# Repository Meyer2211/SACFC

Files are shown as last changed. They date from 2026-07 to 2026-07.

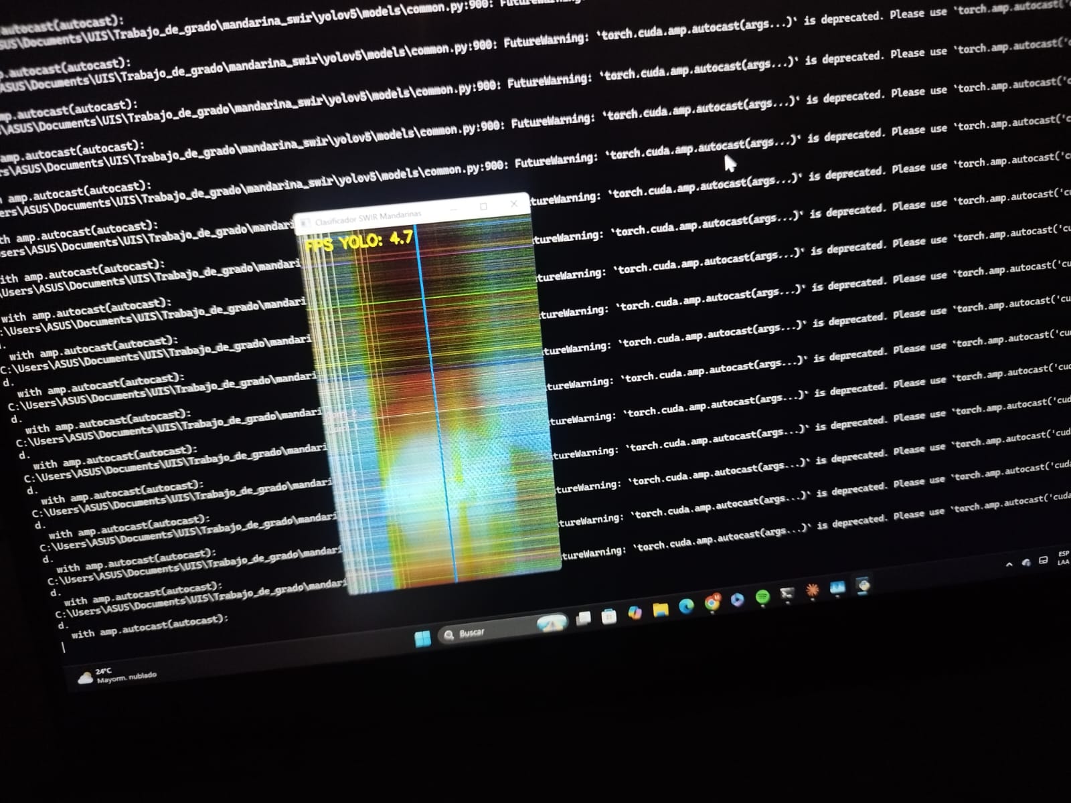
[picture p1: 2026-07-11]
SWIR/Pruebas_del_sistema_02_06_26/2_02_06_26.jpeg

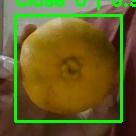
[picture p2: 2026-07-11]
RGB/Pruebas_Obtenidas/Image_processing/PAD_Dinamico/mandarina_3_MALA.jpg

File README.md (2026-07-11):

# SACFC

## Sistema Automático de Clasificación de Frutos Cítricos

## Descripción general

Este repositorio contiene el desarrollo de un trabajo de grado universitario centrado en un sistema de clasificación automática de mandarinas en tiempo real, orientado a una línea de banda transportadora. El sistema combina visión por computador para la detección y evaluación de calidad de la fruta con actuadores físicos (servomotores controlados por Arduino) para desviarla hacia carriles de fruta "buena" o "mala" según el resultado de la clasificación.

## Objetivo del proyecto

Diseñar e implementar un sistema capaz de detectar mandarinas sobre una banda transportadora, clasificar su calidad de forma automática y accionar físicamente su desvío hacia el carril correspondiente, operando en tiempo real durante el proceso de selección.

## Estructura general del repositorio

```
SACFC/
├── SWIR/
├── RGB/
└── Impresiones_3D/
```

El repositorio agrupa el trabajo en tres áreas principales:

- **`SWIR/`** — Sistema actual del proyecto, basado en una cámara hiperespectral SWIR (infrarrojo de onda corta) de tipo *pushbroom*. Es el subsistema en desarrollo activo y el que concentra la mayor parte del trabajo reciente.
- **`RGB/`** — Prototipo inicial del proyecto, desarrollado con una cámara RGB estándar. Corresponde a una etapa exploratoria y anterior, que sirvió de base conceptual antes de migrar al enfoque hiperespectral.
- **`Impresiones_3D/`** — Archivos de diseño para las piezas mecánicas impresas en 3D utilizadas en los mecanismos de actuación (puertas/desviadores) de la banda transportadora. No contiene código.

## RGB vs. SWIR

Ambas carpetas representan el mismo objetivo de clasificación, pero abordado con tecnologías de captura distintas y en momentos distintos del proyecto:

- **RGB** utiliza una cámara de color convencional y representa la fase exploratoria inicial del trabajo de grado.
- **SWIR** utiliza una cámara hiperespectral pushbroom, que captura información espectral adicional a la visible, y representa la evolución del proyecto hacia una solución más robusta.

**El desarrollo activo del proyecto se encuentra en `SWIR/`.** El contenido de `RGB/` se conserva como referencia histórica del proceso, pero no recibe mantenimiento continuo.

## Impresiones 3D

La carpeta `Impresiones_3D/` reúne los archivos STL y recursos de terceros asociados a las piezas mecánicas del sistema, correspondientes a los mecanismos físicos de desvío de fruta sobre la banda transportadora. No forma parte del código del sistema.

## Estado del proyecto

Este repositorio corresponde a un trabajo de grado en desarrollo. La documentación específica de cada subsistema, su arquitectura interna y sus instrucciones de ejecución se encuentran en los README de las carpetas correspondientes (`SWIR/Pushbroom/README.md` y `RGB/README.md`).

## Documentación

Cada subsistema dispone de su propio README con el detalle de su arquitectura, estructura interna y (cuando aplica) instrucciones de ejecución.

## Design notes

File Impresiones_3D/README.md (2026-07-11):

# Impresiones_3D

## Propósito

Esta carpeta reúne los recursos de diseño mecánico utilizados para fabricar, mediante impresión 3D, las piezas físicas de los mecanismos de actuación (puertas/desviadores) del sistema de clasificación de mandarinas.

## Contenido

- **Archivos STL** — modelos 3D listos para impresión, correspondientes a las piezas del mecanismo de desvío diseñadas para este proyecto.
- **Archivos de terceros** — paquetes descargados de repositorios de diseño externos, con mecanismos de referencia (puertas accionadas por servo, actuadores lineales por servo) utilizados como base o inspiración para el diseño propio.

## Relación con el sistema de clasificación

Las piezas contenidas en esta carpeta forman el mecanismo físico que el sistema activa para desviar cada mandarina hacia el carril correspondiente ("buena" o "mala") sobre la banda transportadora, según la clasificación producida por el software. Estas piezas son accionadas por los servomotores que el sistema controla mediante Arduino.

## Alcance

Esta carpeta no contiene código fuente del sistema. Su contenido corresponde exclusivamente a diseño mecánico y recursos de terceros asociados a la fabricación física de los mecanismos de actuación.

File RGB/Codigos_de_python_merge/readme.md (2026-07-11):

En esta carpeta se encuentran todos los scripts desarrollados en Python para las distintas etapas del sistema.

Los archivos están organizados según el nivel de integración alcanzado en cada fase:

🔹 1. Procesamiento con YOLO
Scripts dedicados únicamente a:

Captura de imagen desde la cámara.

Detección de mandarinas mediante YOLOv5.

Visualización de bounding boxes.

Validación de coordenadas.

🔹 2. YOLO + Red de Clasificación
En esta etapa se integró:

Detección con YOLOv5.

Recorte automático usando las coordenadas detectadas.

Conversión de color (BGR → RGB).

Clasificación de calidad mediante la red en TensorFlow.

Visualización de la etiqueta (Buena / Mala).

🔹 3. YOLO + Red + Arduino
Fase de integración más completa del sistema, donde:

Se detecta la mandarina.

Se clasifica su calidad.

Se envía la decisión al Arduino.

Se ejecuta la acción física mediante servomotores.

Esta etapa representa la base funcional del sistema en tiempo real previo a optimizaciones finales.

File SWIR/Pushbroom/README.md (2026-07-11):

# Sistema de Clasificación SWIR — Mandarinas

## Estructura del proyecto

```
mandarina_swir/
├── config.py           ← TODOS los parámetros modificables (leer primero)
├── camera.py           ← Adquisición gxipy + extracción de bandas
├── buffer.py           ← Rolling window con sincronización temporal
├── preprocessing.py    ← Preprocesamiento Vy: norm por canal + gamma (compartido)
├── pseudo_rgb.py       ← Construcción pseudo-RGB para YOLO y display
├── detector.py         ← Wrapper YOLOv5
├── classifier.py       ← Clasificador intercambiable (pkl / h5 / pt)
├── tracker.py          ← Tracker multi-objeto (Y + área + IoU)
├── actuator.py         ← Cola FIFO + serial Arduino
├── main.py             ← Orquestador + hilos + visualización
├── requirements.txt
└── arduino/
    └── servo_control.ino
```

## Instalación

```bash
pip install -r requirements.txt
# Instalar gxipy manualmente desde el SDK de Daheng Imaging
```

## Uso

```bash
# Con cámara real
python main.py

# Modo simulado (sin hardware)
python main.py --sim
```

## Parámetro crítico por sesión

**Antes de cada sesión de laboratorio**, detectar el pico espectral del lote actual:

```bash
python detectar_pico.py --cubo cubos_prueba/<nombre>.npy
```

Luego actualizar en `config.py`:

```python
SPECTRAL_PEAK_BAND: int = <valor_detectado>  # único parámetro que cambia por sesión
```

Las bandas absolutas y el pseudo-RGB se recalculan automáticamente a partir de este valor.

## Calibración de parámetros mecánicos

Editar en `config.py`:

| Parámetro | Descripción |
|---|---|
| `RPM_BANDA` | Medir con tacómetro en el motor |
| `DIAMETRO_RODILLO_CM` | Medir con calibrador en el rodillo |
| `DISTANCIA_CAMARA_COMPUERTA_CM` | Medir con cinta métrica |

## Representación espectral Vy (NO modificar sin reentrenar)

Los offsets y parámetros de preprocesamiento están congelados en `config.py`:

| Parámetro | Valor | Descripción |
|---|---|---|
| `OFFSETS_STACK` | `[+11, +2, -5, -10, -3]` | Offsets relativos al pico para los 5 canales |
| `PSEUDO_RGB_BAND_INDICES` | `[0, 1, 2]` | Canales R, G, B dentro del stack |
| `PREP_P_LOW` | `1.0` | Percentil inferior de normalización por canal |
| `PREP_P_HIGH` | `99.5` | Percentil superior de normalización por canal |
| `PREP_GAMMA` | `1.440` | Corrección gamma aplicada después de normalizar |
| `BACKGROUND_CORRECTION_ON` | `False` | OFF validado experimentalmente con Vy |

## Visualización

La ventana de tamaño fijo se configura en `config.py`:

| Parámetro | Valor por defecto | Descripción |
|---|---|---|
| `WINDOW_WIDTH` | `1600` | Ancho total de la ventana en píxeles |
| `WINDOW_HEIGHT` | `900` | Alto total de la ventana en píxeles |
| `RIGHT_PANEL_WIDTH` | `320` | Ancho fijo del panel de estado |

El panel izquierdo muestra el pseudo-RGB en tiempo real con bboxes y etiquetas.
El panel derecho muestra última clasificación, contadores de sesión, estado de módulos
y configuración activa. El diseño no se deforma si cambia el tamaño del buffer.

## Cambiar clasificador

En `config.py`:

```python
# Para RF+GLCM (.pkl sklearn Pipeline)
CLASSIFIER_TYPE = "pkl_rf_glcm"
CLASSIFIER_MODEL_PATH = "rf_glcm_5ch.pkl"

# Para CNN Keras (.h5)
CLASSIFIER_TYPE = "h5_cnn"
CLASSIFIER_MODEL_PATH = "cnn_5ch.h5"
```

El preprocesamiento Vy (normalización por canal + gamma) se aplica en
`preprocessing.py` antes de entregar los datos al modelo — no dentro del
clasificador. Cambiar el modelo no requiere modificar el preprocesamiento.

## Arquitectura de hilos

```
Hilo Cámara      → cola_camara     → Loop Principal
Loop Principal   → buffer          → get_frame() → pseudo_rgb.py → YOLO → Tracker
Tracker          → cola_clasif.    → Hilo Clasificador
Hilo Clasif.     → preprocessing.py → clasificador → cola_resultados
Loop Principal   → cola_resultados → Actuador → Serial Arduino
Loop Principal   → canvas fijo     → cv2.imshow
```

## Flujo de preprocesamiento Vy

```
Frame crudo del buffer
      ↓
preprocessing.preprocess_channels()
      ├── norm por canal (percentil 1 / 99.5)
      ├── clip [0, 1]
      └── gamma 1.440
      ↓
┌─────────────────────────────────┐
│ Ruta YOLO/display               │  → uint8 (*255) → YOLO + visualización
│ canales [0, 1, 2] (R, G, B)    │
└─────────────────────────────────┘
┌─────────────────────────────────┐
│ Ruta CNN                        │  → float32 en [0,1] → clasificador
│ canales [0, 1, 2, 3, 4]        │
└─────────────────────────────────┘
```

La misma función matemática se aplica en ambas rutas.
YOLO y la CNN siempre reciben datos preprocesados idénticamente.

## Supuesto operativo crítico

La velocidad de la banda se asume **constante**. Variaciones de velocidad
deforman el pseudo-RGB y afectan el timing del servo. Si la banda
experimenta variaciones de velocidad, recalibrar `RPM_BANDA` o implementar
un encoder de velocidad en futuras versiones.

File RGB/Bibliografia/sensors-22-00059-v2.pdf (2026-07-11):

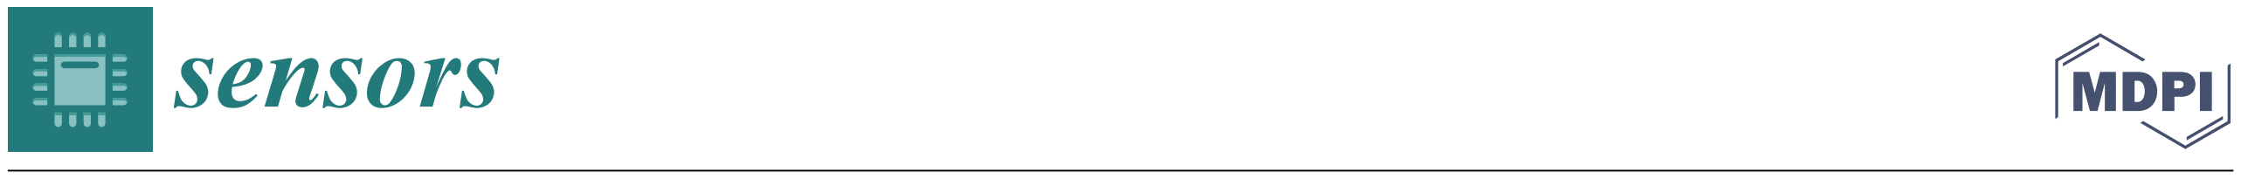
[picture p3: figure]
sensors

(https://www.mdpi.com/article/10.3390/s22010059?type=check_update&version=2)

Citation: Huang, H.; Huang, T.; Li, Z.; Lyu, S.; Hong, T. Design of Citrus Fruit Detection System Based on Mobile Platform and Edge Computer Device. Sensors 2022, 22, 59. https://doi.org/10.3390/s22010059

Academic Editor: Gemine Vivone

Received: 30 November 2021 Accepted: 20 December 2021 Published: 23 December 2021

Publisher’s Note: MDPI stays neutral with regard to jurisdictional claims in published maps and institutional affiliations.

Copyright: © 2021 by the authors. Licensee MDPI, Basel, Switzerland. This article is an open access article distributed under the terms and conditions of the Creative Commons Attribution (CC BY) license (https://creativecommons.org/licenses/by/4.0/).

Article

# Design of Citrus Fruit Detection System Based on Mobile Platform and Edge Computer Device

Heqing Huang 1,2, Tongbin Huang 1,2, Zhen Li 1,2,3,4,*, Shilei Lyu 1,2,4 and Tao Hong 5

1 | College of Electronic Engineering (College of Artificial Intelligence), South China Agricultural University,
| Guangzhou 510642, China; huangheqing@stu.scau.edu.cn (H.H.); 20203163156@stu.scau.edu.cn (T.H.);
| lvshilei@scau.edu.cn (S.L.)
2 | National Research Laboratory of Mechanization of Citrus Industry Technical System,
| Guangzhou 510642, China
3 | Guangdong Agricultural Information Monitoring Engineering and Technology Research Center,
| Guangzhou 510642, China
4 | Pazhou Lab, Guangzhou 510330, China
5 | School of Electronic and Information Engineering, Beihang University, Beijing 100190, China;
| hongtao@buaa.edu.cn
* | Correspondence: Lizhen@scau.edu.cn

Abstract: Citrus fruit detection can provide technical support for fine management and yield determination of citrus orchards. Accurate detection of citrus fruits in mountain orchards is challenging because of leaf occlusion and citrus fruit mutual occlusion of different fruits. This paper presents a citrus detection task that combines UAV data collection, AI embedded device, and target detection algorithm. The system used a small unmanned aerial vehicle equipped with a camera to take full-scale pictures of citrus trees; at the same time, we extended the state-of-the-art model target detection algorithm, added the attention mechanism and adaptive fusion feature method, improved the model’s performance; to facilitate the deployment of the model, we used the pruning method to reduce the amount of model calculation and parameters. The improved target detection algorithm is ported to the edge computing end to detect the data collected by the unmanned aerial vehicle. The experiment was performed on the self-made citrus dataset, the detection accuracy was 93.32%, and the processing speed at the edge computing device was 180 ms/frame. This method is suitable for citrus detection tasks in the mountainous orchard environment, and it can help fruit growers to estimate their yield.

Keywords: citrus detection; UAV; mobile operation platforms; edge computing devices

### 1. Introduction

Citrus is the largest fruit in the world and one of the main cash crops. With the gradual increase of citrus yield every year, the planting range is also gradually expanded, people pay more attention to this highly nutritious fruit. In this case, fruit farmers’ yield increase, and yield estimation play a role in economic income generation. Target detection algorithm can provide technical support for these citrus tasks. In recent years, it has been widely used in citrus operations [1], such as citrus picking [2], orchard yield measurement [3]. At present, the target detection network built by the deep and wide convolutional neural network has ideal recognition accuracy and real-time performance. Still, many deep and wide target detection algorithms need to process on the server with high configuration. A large amount of memory consumption and existing occupation make running on the edge computing platform; on the other hand, in the actual mountain orchard environment, with undulating terrain, complex terrain, and different soil thickness, it is dangerously challenging to collect citrus data. At the same time, the data taken by the regular use of the mobile camera is relatively single, which is greatly affected by the site, thus affecting the judgment of fruit farmers on the estimation of citrus yield. Therefore, it is of great significance to study

Sensors 2022, 22, 59. https://doi.org/10.3390/s22010059 | https://www.mdpi.com/journal/sensors

Sensors 2022, 22, 59 | 2 of 14

the acquisition and transmission of citrus images on the mobile operating platform/UAV and realize the accurate recognition of citrus targets for the fine management and yield estimation of orchards.
The traditional machine learning method [4,5] is not ideal for target recognition, and neither speed nor precision can meet the actual needs. In 2012, the proposal of convolutional neural network [6] promoted the upsurge of deep learning, and many target detection models [7] were proposed. At present, target detection algorithms can divide into two categories. One is based on anchor-free type; the main methods are FCOS [8], Centernet [9], etc., instead of setting anchor boxes artificially, objects are detected by point regression. The other is based on anchor-based, which is more used, such as YOLO [10,11], SSD [12], etc., by setting anchor boxes with different sizes and proportions for each pixel. Specifically, the anchor-based target detection algorithm takes the anchor as the detection starting point, corrects the position and category of the anchor, and obtains the results; this kind of algorithm needs to manually set more parameters, which can more effectively get the prior knowledge of the data set and make the model converge faster. The anchor-free target detection algorithm uses anchor points and key points to pair the objects to be detected; this method reduces the parameters, simplifies the calculation process of the algorithm, and can achieve good results in speed and accuracy.
In the detection task in the agricultural field, SA et al. [13] used the transfer learning method to fine-tune the weight of pre-training and detect the fruit, this method takes into account the detection accuracy and recall, but the model training time is long; Tian et al. [14] used the improved YOLOv3 detection algorithm to process high-resolution image data in real-time, which can quickly detect fruits in orchards; Chen et al. [15] proposed an unsupervised learning method, which uses the target detection algorithm in deep learning to learn plane features, which solves the problem of slow traditional recognition and matching methods; Kurtulmus et al. [16] extracted and fused multi-scale features from citrus images to obtain high detection accuracy, but added multi-stage complex search strategy will reduce the detection speed of the model.
With the update of hardware devices, many high-performance sensors are widely used [17,18]. In some specific scenarios, these low-power and portable devices may play an important role, to obtain crop information accurately and timely. Fan et al. [19] used UAV low altitude remote sensing technology to obtain crop images with different resolutions, summarized the research and application of crop growth trend, yield estimation, pest, and forage monitoring, and achieved good results; Liu et al. [20] proposed to transform the model based on color space, segment the foreground (crop) and background (soil background) of UAV image, obtain the classified binary image of the image, and then extract the plant number information of corn seedling image by skeleton extraction algorithm. Some studies have deployed target detection algorithms to edge computing devices to complete different tasks [21–23]. In orchard scenarios, accurate real-time detection or classification goals effectively judge crop health and yield-related management. Mazzia et al. [24] implemented the YOLOv3-Tiny target detection algorithm on different embedded platforms. The proposed edge segment solution can deploy on unmanned ground vehicles, and the apples in the orchard can be detected and counted in real-time with a detection accuracy of 83.64%. SA et al. [25] trained six models by adjusting the number of channels in different depths and widths of the target detection model to detect weeds on Jetson TX2 to reduce damage to surrounding plants.
We presented a citrus fruit recognition method based on a deep learning target detection model, mobile data platform, and edge computing device. Specifically, we place an unmanned aerial vehicle in the orchard to collect citrus images from all directions around the citrus tree. These data are transmitted to the edge computing device Jetson nano via 4G data transfer. An improved target detection algorithm is deployed inside the device. To solve the problem that it is difficult to balance the accuracy and real-time of target detection algorithm in edge computing device, the state-of-the-art model was improved the structure of the model by adding a convolution module (CBAM) [26] with an attention mechanism;

fusion of feature maps with different resolutions using adaptive parameters [27]; finally, with the accuracy guaranteed, we prune the model weights, add L2 regularization constraints to the batch normalization layer, delete and fine-tune the 30% redundant channels that occupy the minor information in the channels. In the experimental part, the feasibility of the proposed method proves by ablation experiments of the model itself and comparison experiments with other models.
The main contributions of this paper are as follows:
(1) Combined with the advantages of the mobile operating platform and edge computing equipment, the improved deep learning target detection model is used to accurately and real-time detect the omni-directional citrus fruit image taken by UAV.
(2) The target detection algorithm was improved and optimized. Attention mechanism, multi-layer feature adaptive fusion, and pruning optimization are adopted to improve the accuracy and reasoning speed of the model.

### 2. Data Acquisition and System Design

2.1. Collection and Transmission of Citrus Fruit Data Set
The scene of UAV shooting citrus fruit image is shown in Figure 1. To obtain citrus images in a mountain orchard environment, on the one hand, we need some necessary hardware equipment, such as a camera, power supply, visual display screen, and edge computing equipment, to recognize citrus images. On the other hand, while obtaining the above information, the rational use of UAV technology can help fruit farmers monitor citrus fruits in an all-around way, improve orchard management efficiency, and assist in yield estimation. The UAV equipment used in this paper is Mavic air 2, it is produced by Dajiang and released on 28 April 2020, which can take high-pixel photos and fly at low altitudes for one hour. The main task of the UAV is to collect image data about 1 m above the citrus fruit tree and upload the image to the edge computer device. The image is further processed by using the target detection algorithm to achieve the real-time detection effect of citrus fruit.

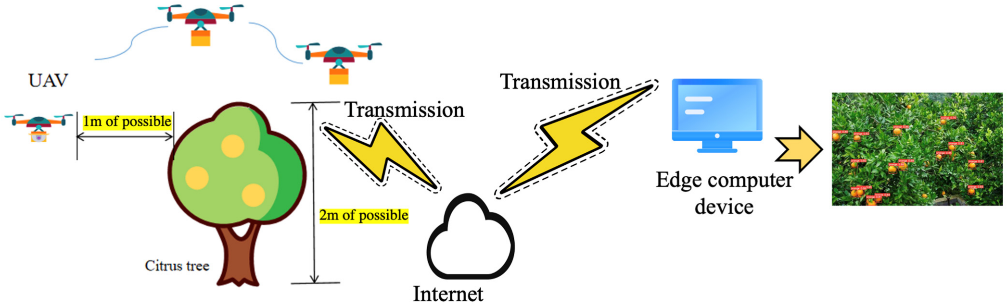
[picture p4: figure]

Figure 1. UAV device for taking citrus images. The citrus tree is about 2 m high. We used UAV to collect images in an all-round way at about 1 m around the fruit tree.

UAV capture image has high security and flexibility. The change of environment has little impact on its image acquisition, and the image acquisition cycle is also short, which improves work efficiency and reduces the labor cost. Figure 2 depicts the process of capturing citrus images using UAV. First, we used the camera carried on the UAV to capture the citrus image, transmit it to the edge computing device through the wireless network. Then, we used the deployed target detection algorithm to detect the citrus and visualize it through the display device.

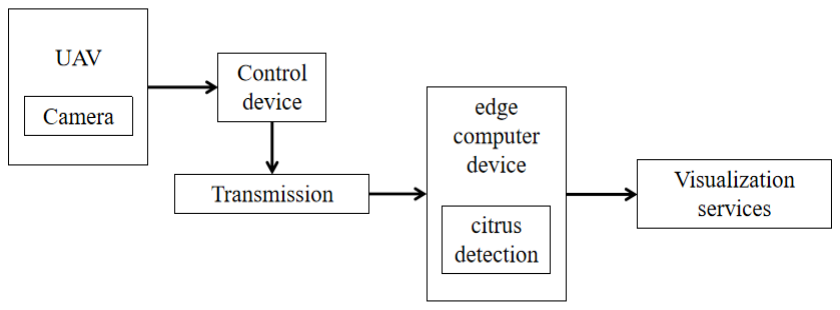
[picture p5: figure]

Figure 2. Citrus image shooting and transmission process.

We used the self-made citrus data set to train the model provided in this paper and collected data in the citrus orchard in Yizhang County, Hunan Province, China. A total of 1800 citrus fruit images taken by mobile camera and UAV low altitude aerial photography, about 1 m away from citrus fruit trees, and annotated manually with LabelImg. The dataset system is used as a format for coco datasets to standardize training data. We selected 400 aerial images as the test set, 1300 citrus images as the training set, and 100 as the verification set. We note that the problem of leaf occlusion and citrus fruit occlusion significantly impacts the recognition effect. The test set is manually divided into two parts: A and B. A test set contains 250 slightly occluded citrus fruit images, and the B test set includes 150 severely occluded citrus fruit images.

2.2. Data Enhancement
To strengthen the richness of training samples’ richness and increase model robustness, three data enhancement methods are used in this paper, namely Mixup, Cutout, and Cutmix. Mixup randomly selects two images from the training samples and mixes them in proportion but does not affect the labeling results. Cutout randomly cuts out a particular area in the chosen image and fills in a specific pixel value, which does not affect the labeled result. Cutmix randomly cuts the samples in the training set, but does not fill in fixed pixel values and uses another randomly selected sample area to fill in the image quality. In the citrus dataset, there are severe problems of mutual occlusion and leaf occlusion between citrus. Through data enhancement, the model is more inclined to recognize objects from local images, enhance the model’s positioning ability, and improve the robustness.
2.3. Design of Edge Computing Device
The hardware equipment of the citrus fruit recognition system is mainly composed of an edge computing development board, display screen required for visualization, external camera, and power supply module. We deployed the target detection model to Jetson nano for reasoning, which is a portable development version of artificial intelligence released by NVIDIA. It contains 128 core Maxwell architecture GPU and fast reasoning speed in 5 W/10 W low-power model, has rich AI programming neurons, and speeds up the speed of deep learning algorithm for equipment operation. The operating system is Ubuntu 18.04. The platform power supply module is 5000 mAh, 12 V equalizing rechargeable lithium battery; powerful computing power and small platform design are conducive to the design of portable citrus fruit target detection system. Figure 3 shows an example diagram of an edge computing device for detecting citrus fruits.

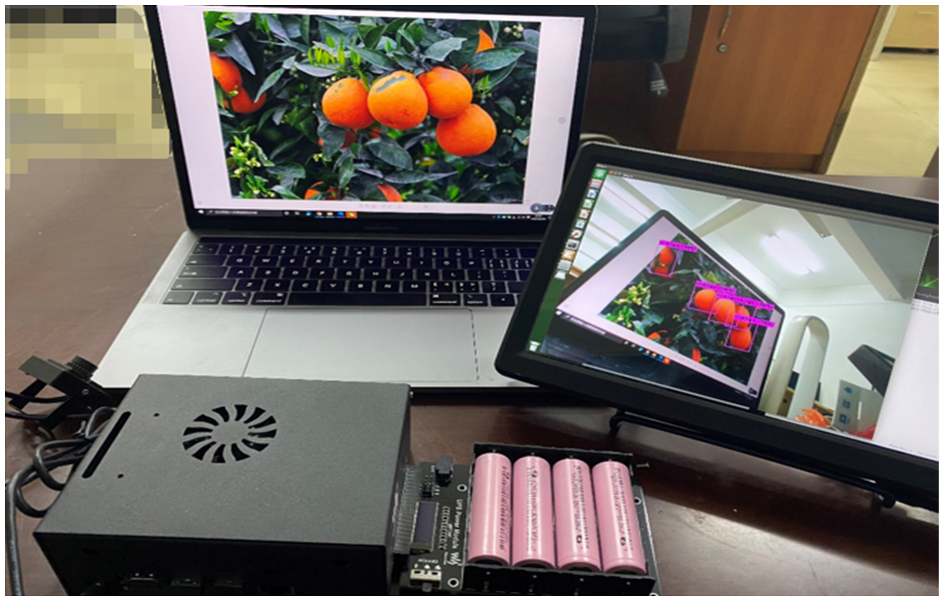
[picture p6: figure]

Figure 3. Portable edge computing device with a small visual display, mobile power supply, camera, Jetson nano, and internal target detection model.

### 3. Construction of Citrus Target Recognition Model

3.1. Basic Model Selection
YOLOv5 is a one-stage target detection algorithm that combines detection speed and detection accuracy. The detection network has four versions, in turn, YOLOv5x, YOLOv5l, YOLOv5m, YOLOv5s. Among them, YOLOv5s is the network with the minor depth and width of the feature map, and the other three can be based on it, which has been deepened and widened.
Considering the accuracy and real-time of the citrus fruit detection model in edge computing device deployment, we used YOLO5s with minor parameters and the fastest speed as the benchmark of the detection model. Structurally, the model first increased the Focus structure; the core of this structure is to slice pictures, change the size of the feature map of the input image, use many residual CSP structures, enhance the learning ability of the model; add a variety of data enhancement operations. In the training process, the drop block is used to prevent overfitting. As for the drop block method, it is suitable for the regularization of the convolution layer, and the adjacent areas on the feature map of a layer are deleted together, rather than independent pixels. Therefore, the model will pay more attention to other places to fit the data. The loss function used the CIoU border loss function constraint model, the overall architecture shown in Figure 4.

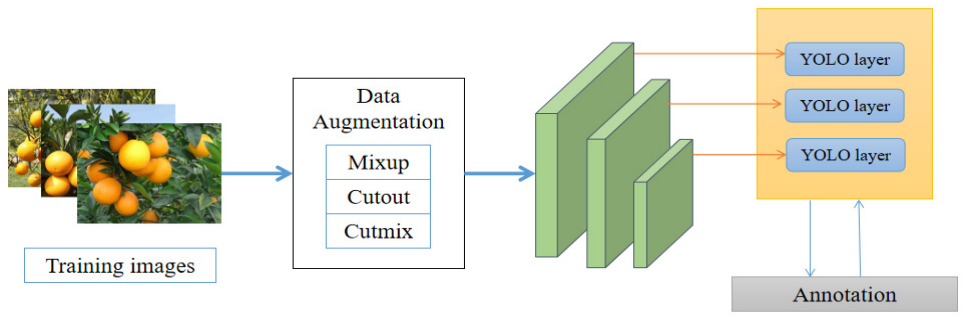
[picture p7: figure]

Figure 4. The YOLOv5 model structure diagram. We used three data enhancement methods during training.

3.2. Module Design of Attention Mechanism
When detecting the images captured by UAV low altitude aerial photography, due to the difficulty in grasping the flight height and the uncertain scale transformation of the collected data, which is easy to cause the problem of significant differences of citrus size in different images, at the same time, there are some problems between different citrus, such as mutual occlusion and leaf coverage, which makes it a great challenge to detect such data. This paper used a lightweight attention mechanism module CBAM to strengthen attention to occluded objects. This architecture is inserted into many CNN models without disturbing the model training steps. Through the feature map output by the model, the attention mechanism carries out in channel and space simultaneously. The architecture diagram of CBAM is shown in Figure 5.

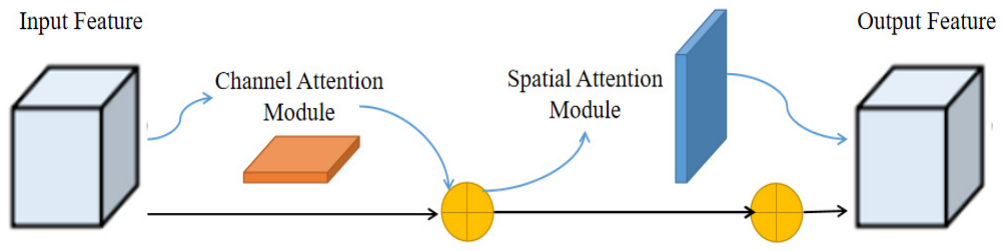
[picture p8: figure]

Figure 5. CBAM architecture is shown in the figure, which is composed of two serial modules: channel attention and spatial attention.

Among them, the formula for calculating channel attention is shown in Equation (1). The input characteristic map is obtained by global pooling operation and average pooling operation of width and height, respectively. Then, they are sent to a two-layer neural network to share parameters at the same time. After fusion, they activate by sigmoid activation function to generate the characteristic map required for channel attention.

Mc(F) = σ(MLP(Avgpool(F)) + MLP(Maxpool(F))) | (1)

The formula for calculating spatial attention is shown in Equation (2). The feature mapping and original mapping of computational channel attention fusion are used to calculate spatial attention. Perform global average/maximum pool operation on the channel to obtain feature mapping; this structure uses concat to fuse the features of the two processes, and the final feature mapping is obtained through the sigmoid process.

Ms(F) = σ(f

7×7
([Avgpool(F); MLP(Maxpool(F)])) | (2)

The insertion of CBAM in the model structure is shown in Figure 6, and we added CBAM to the feature pyramid before each extracted feature fusion to improve the model performance.

Sensors 2022 ,

22, 59 | 7 of 14

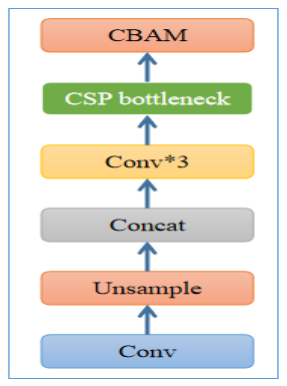
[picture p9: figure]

Figure 6. The CBAM model was added to each basic block, which integrates the output features immediately after the CSP bottleneck. Among them, Conv * 3 means that three convolution layers are superimposed together.

3.3. Adaptive Feature Fusion
Feature pyramid (FPN) is a standard structure for a target detection network to extract features with different resolutions. However, various scale features are processed separately without interaction, which limits the performance of the model. In the citrus dataset, there are many small target citrus fruits, which need to refine and reuse the underlying features. This paper used a fusion method for additional resolution features, called adaptive spatial feature fusion (ASFF). By learning to adaptively adjust the spatial weight of each scale feature during fusion, the scale invariance of the feature is improved. ASFF structure diagram is shown in Figure 7.

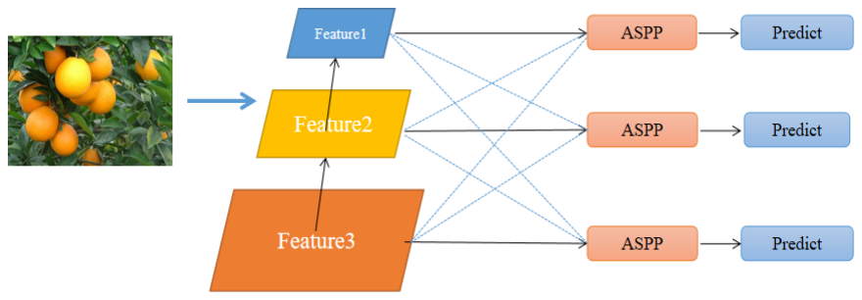
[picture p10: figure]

Figure 7. The feature map output from the model is fused adaptively.

The formula of feature fusion of this method is shown in Equation (3). Where x

1
ij
is the feature map of different feature layers, with three feature parameters α, β and γ. We used the three-layer features to multiply the weight parameters to obtain new fusion features. This structure has a good detection effect on small targets. We make full use of the fine-grained features in the underlying structure to identify small objects.

y

1
ij = α

1
ij·x

1
ij+β

1
ij·x

2
ij+γ

1
ij·x

3
ij | (3)

3.4. Model Pruning
Although the improved citrus detection network performs well in detection accuracy, it still has limitations when transplanted to Jetson nano edge computing equipment. To meet the diversity of different data distributions, the model will set many channels to extract rich features. However, the data features are relatively single for the citrus data set and do not need too many channels to fit the data. That is, there are many redundant parameters in the model, and not every channel in the characteristic diagram contains valuable information. In this section, we used the method of pruning the number of model channels to reduce the amount of calculation and parameters of the model, speed up the reasoning speed, and ensure the model’s accuracy through fine-tuning.
The batch normalization layer (BN) can forcibly pull back the deviation distribution in model training and then standardize it into the numerical level of normal distribution of mean and variance, which makes the activation function more sensitive and speeds up the training speed of the model. The calculation formula of BN layer is shown in Formulas (4) and (5). Activation size zˆout and coefficient of each channel γ positive correlation, if γ too small, close to 0, the activation value is also very small.

zˆi = q

zin − µB

σ

2
B + e

(4)

zˆout =γzˆi + β | (5)

We used L2 regularization to constrain the parameters of the batch normalization layer for thinning and feature selection. After training a network normally, the coefficients of the BN layer are normally distributed, and adding L2 regularization to the loss function can make the weight value sparse and gradually approach 0. When the first training, redundant channels and features are selected by pruning, and relatively light feature weights are filtered and deleted. After convolution, the corresponding activation values of these channels are also relatively small. L2 regularization formula is shown in Equation (6).

L = Ein + γ∑

j

w²
j
| (6)

where L represents the sum of squares of weights added to the original loss and represents the square summation of each neuron in the vector weight, where E represents the training sample error without regularization, and w is the weight value in the model, which can be limited to 0, which can control the regularization trend. When the parameters increase, the model complexity will be constrained to a large extent. After pruning, the accuracy is restored by fine tuning.
The pruning process is shown in Figure 8. It is divided into three steps: training pruning fine-tuning. Firstly, the original model is used to train the citrus data set to obtain the weight; Taking the scaling factor in BN as a reference, L2 filters the weight value and deletes the number of channels whose weight is less than a certain threshold. Change the number of channels in the model network, make full use of the advantages of dense connection of convolution network, minimize the redundant channels and retrain.

Sensors 2022 , 22, 59 | 9 of 14

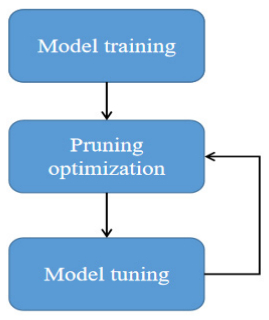
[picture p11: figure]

Figure 8. Model pruning process, to ensure accuracy, the model used in this paper is optimized twice.

### 4. Experiment and Results

In this part, firstly, we introduced the training details and methods used in this paper. Secondly, we designed ablation experiments and comparative experiments of different test sets on the improved model and evaluated on the edge computing equipment. Finally, we did a comparative experiment with the same advanced target detection algorithm. At the end of this section, we visualize the effect of citrus fruit recognition.

4.1. Experimental Training Setting
We used the transfer learning method to load the pre-train weight so that the model has stable parameters for training from the beginning, which speeds up the training speed and reduces the amount of data required for model fitting. The default input image resolution of the model is 608 pixel × 608 pixel × 3. Because there is only one category in the citrus dataset, the default feature dimension is 18.
In training, we trained 50 epochs on the citrus data set, and set the constraint model using CIoU loss function and adam optimization algorithm β1 = 0.89, β2 = 0.99, ε = 109. Set batch size to eight. All training was conducted on NVIDIA RTX 2080 Ti graphics card. We used the operating system is Ubuntu 18.04, and the in-depth learning parallel acceleration Library of cuda10.2 and cudnn8.0 is used for acceleration training; PyTorch version is 1.7.
4.2. Ablation Experiment
We used the average accuracy, the detection speed of a single picture in Jetson nano, and the recall as the evaluation indexes. Formulas (7)–(9) is the calculation method of the average accuracy. Among them, average accuracy is a popular evaluation method of the target detection model, which is used to evaluate whether the model detects objects in the image accurately.
P =

TP
TP + FP
× 100% | (7)

R =

TP
TP + FN
× 100% | (8)

R =

TP
TP + FN
× 100% | (9)

where P is the correct rate (%), R is the recall rate (%), TP is the real-positive sample, FP is the false-positive sample, and FN is the false-negative sample.
To understand the model performance and prove the effectiveness of the optimized model in this paper, we compared each improved part and conducted the ablation experiment of the model on all citrus test set, as shown in Table 1.

Table 1. Model Ablation Experiment.

Model | AP/% | Speed/ms | Recall/%
YOLOv5s | 91.03 | 270 | 87.13
YOLOv5s + CBAM | 93.42 | 310 | 88.21
YOLOv5s + CBAM + ASFF | 93.86 | 320 | 88.91
YOLOv5s + CBAM + ASFF + Purning | 93.32 | 180 | 88.78

It can be seen from the table that after adding the CBAM module, the detection accuracy of the model is improved by 2.39%, but the detection time is increased by 40 ms. After adding ASFF, the detection accuracy is improved by 0.44%. To recover and speed up the reasoning speed of the model, the detection speed of citrus by the pruned model is 180 ms/frame.
In this paper, to ensure the accuracy of the model, we use twice pruning to optimize the model, compared the results of pruning processes, as shown in the Table 2. After the first pruning, the memory occupied by the model is reduced by 6 M when a small amount of accuracy is lost. After the second pruning, the memory volume of the model is only 21 M, while ensuring accuracy, we reduced the amount of calculation and parameters of the model, which provides convenience for deployment to edge computing devices.

Table 2. Model results of twice pruning.

Model | Model Size/MB | | AP/%
Original | 33 | | 93.86
First | 27 | | 93.55
Second | 21 | | 93.32
4.3. Comparative Test of Different Occlusion Degrees
In this section, we used the improved model to conduct comparative experiments on test sets A and B, respectively, among them, dataset A is the slightly occluded citrus fruit image, and dataset B is the heavily occluded citrus fruit image, the results as shown in Table 3. The recognition accuracy of the improved model for slightly occluded citrus fruit images is 96.01%, which is higher than that of the basic model by 0.57%, and the recognition accuracy of heavily occluded citrus fruit images is 89.41%, which is higher than that of the basic model by 2.55%. Experiments show that the model can improve the detection effect of citrus fruits under different occlusion degrees, which proves the effectiveness of the method proposed in this paper.

Table 3. Comparison of citrus fruit data sets with different occlusion degrees.

Model | Dataset. A (AP/%) | Dataset. B (AP/%)
Original | 95.44 | | 87.86
Ours | 96.01 | | 90.41
4.4. Comparative Experiment of Different Target Detection Models
We have carried out comparative experiments with the same advanced target detection models, including FCOS, YOLOv4, and YOLOv3, as shown in Table 4. The accuracy of our improved model is higher than that of other baselines. Similarly, the detection speed in 2080Ti is 83 FPS/s, which is increased by 10 and 14 FPS/s, respectively, compared with YOLOv4 and YOLOv3.

Table 4. Model comparison experiment.

Model | AP/% | FPS (In 2080ti)/s
FCOS | 90.76 | 47
YOLOv3 | 91.21 | 69
YOLOv4 | 91.97 | 73
Ours | 93.32 | 83

Figure 9 visualizes the effect of our citrus detection model. We showed the detection effect of citrus fruits with mild occlusion and severe occlusion, respectively.

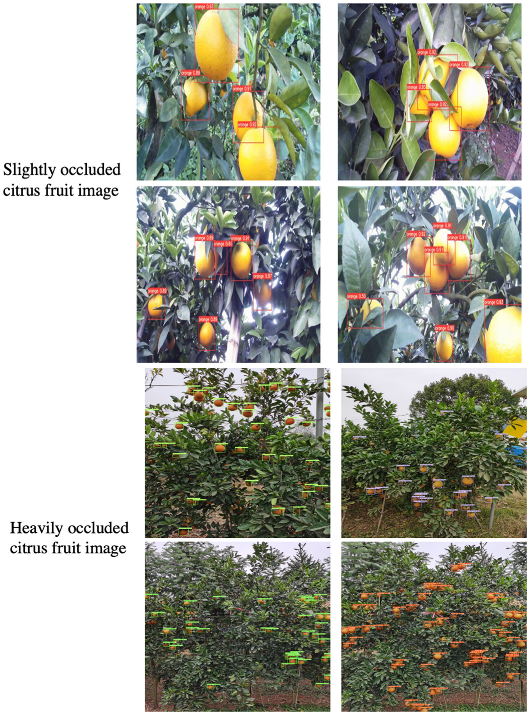
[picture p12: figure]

Figure 9. We visualized the detection effect of citrus fruits under different occlusion levels, In the figure, the words above all detected citrus fruits are "orange" and their confidence.

### 5. Conclusions

We designed a real-time citrus fruit detection system combining a mobile operation platform and edge computing equipment to solve the problems of inconvenient data capture in mountain orchards and the unbalanced speed and accuracy of the target detection model at the edge. By expanding the current most advanced target detection network and improving its feature extraction and reasoning ability, the citrus fruit image data collected by UAV is detected on the edge computing equipment. The test results show that when there are targets with different degrees of occlusion in the natural orchard environment, the accuracy and detection speed of the model are up, which is improved compared with the original baseline. Specifically, we carry out real-time target detection at the edge in the currently popular UAV captured image scene, which is suitable for working in different environments. The main contributions of this paper are as follows:
1. Benefiting from the strong maneuverability and high security of UAV aerial images, and not limited to the actual scene of Mountain Orchard, we collected and labeled 1800 citrus images for target detection model training.
2. Improve the current most advanced target detection model and use CBAM attention mechanism and data enhancement to improve the generalization and accuracy of the model; At the same time, the L2 regularization method constraint model adds to delete the redundant channel with the minimum weight of 30% and fine-tune it. It is detected in the Jetson nano edge computing device. The results are achieved. While ensuring accuracy, a faster detection speed is achieved.
In this paper, for citrus detects by combining visual algorithm, mobile flight equipment, and edge operation platform, we hope this work can provide some help for fruit farmers to estimate yield and improve the operation efficiency of mountain orchards.

### 6. Discussion and Future Work

It is hard to say that our approach has no drawbacks. We mainly focus on ripe citrus fruits and provide technical support for yield estimation. Still, it can also lead to errors when identifying many immature citrus fruits, turning green leaves into natural citrus. To overcome this problem, we will collect images of citrus fruits with different maturity levels for analysis. In addition, the use of UAV technology equipment in mountain orchards often requires professional control. If the shooting distance is close, the UAV equipment can easily touch the branches, causing the operation to fail. In future work, we will also use UAVs to collect and experiment with citrus fruit images of different heights.
Despite these problems, we are committed to using smart devices such as sensors to reduce human resource consumption. We can purchase the edge computing devices used in this article for only 800 RMB. At the same time, compared with the ground imaging system, UAV can collect fruit data from different parts of citrus tree in an all-round way without the influence of orchard location, geographical conditions, and climatic environment, which can reduce the labor time and operation costs of fruit growers. The results show that our recognition of citrus fruits is still effective.

Author Contributions: Conceptualization, H.H. and Z.L.; validation, H.H.; formal analysis, T.H. (Tongbin Huang); investigation, S.L.; resources, Z.L.; data curation, S.L.; writing—original draft preparation, H.H.; writing—review and editing, Z.L. and T.H. (Tao Hong); visualization, T.H. (Tongbin Huang); supervision, S.L. and T.H. (Tao Hong); project administration, Z.L.; funding acquisition, Z.L. All authors have read and agreed to the published version of the manuscript.

Funding: This research was funded by National Natural Science Foundation of China (31971797); China Agriculture Research System of MOF and MARA (CARS-26); Project of Guangdong Provincial Department of Science and Technology (2021A1515010923); Guangdong Provincial Strategy for Rural Revitalization (Yue Cai Nong [2021] No. 37); Subtopics of National Key R&D Program Projects(2020YFD1000107); Special Funds for the Cultivation of Guangdong College Students’ Scientific and Technological Innovation. (“Climbing Program” Special Funds) (pdjh2020a0083).

Institutional Review Board Statement: Not applicable.

Informed Consent Statement: Not applicable.

Data Availability Statement: Not applicable.

Acknowledgments: The authors would like to thank anonymous reviewers for their criticism and suggestions.

Conflicts of Interest: The authors declare no conflict of interest.

References
1. Xing, S.; Lee, M. Classification Accuracy Improvement for Small-Size Citrus Pests and Diseases Using Bridge Connections in Deep Neural Networks. Sensors 2020, 20, 4992. [CrossRef] (http://doi.org/10.3390/s20174992) [PubMed] (http://www.ncbi.nlm.nih.gov/pubmed/32899200)
2. Harrell, R.C.; Adsit, P.D.; Munilla, R.D.; Slaughter, D.C. Robotic Picking of Citrus. Robotica 1990, 8, 269–278. [CrossRef] (http://doi.org/10.1017/S0263574700000308)
3. Dorj, U.-O.; Lee, M.; Yun, S.-S. An Yield Estimation in Citrus Orchards via Fruit Detection and Counting Using Image Processing. Comput. Electron. Agric. 2017, 140, 103–112. [CrossRef] (http://doi.org/10.1016/j.compag.2017.05.019)
4. Dalal, N.; Triggs, B. Histograms of Oriented Gradients for Human Detection. In Proceedings of the 2005 IEEE Computer Society Conference on Computer Vision and Pattern Recognition (CVPR’05), San Diego, CA, USA, 20–25 June 2005; IEEE: Piscataway, NJ, USA, 2005; Volume 1, pp. 886–893.
5. Zeng, Z.Q.; Yu, H.B.; Xu, H.R.; Xie, Y.Q.; Gao, J. Fast Training Support Vector Machines Using Parallel Sequential Minimal Optimization. In Proceedings of the 2008 3rd International Conference on Intelligent System and Knowledge Engineering, Xiamen, China, 17–19 November 2008; IEEE: Piscataway, NJ, USA, 2008; Volume 1, pp. 997–1001.
6. Krizhevsky, A.; Sutskever, I.; Hinton, G.E. Imagenet Classification with Deep Convolutional Neural Networks. Adv. Neural Inf. Process. Syst. 2012, 25, 1097–1105. [CrossRef] (http://doi.org/10.1145/3065386)
7. Ren, S.; He, K.; Girshick, R.; Sun, J. Faster R-CNN: Towards Real-Time Object Detection with Region Proposal Networks. Adv. Neural Inf. Process. Syst. 2015, 28, 91–99. [CrossRef] (http://doi.org/10.1109/TPAMI.2016.2577031) [PubMed] (http://www.ncbi.nlm.nih.gov/pubmed/27295650)
8. Tian, Z.; Shen, C.; Chen, H.; He, T. FCOS: Fully convolutional One-Stage Object Detection. In Proceedings of the IEEE/CVF International Conference on Computer Vision, Seoul, Korea, 27 October–2 November 2019; pp. 9627–9636.
9. Duan, K.; Bai, S.; Xie, L.; Qi, H.; Huang, Q.; Tian, Q. Centernet: Keypoint Triplets for Object Detection. In Proceedings of the IEEE/CVF International Conference on Computer Vision, Seoul, Korea, 27 October–2 November 2019; pp. 6569–6578.
10. Redmon, J.; Divvala, S.; Girshick, R.; Farhadi, A. You Only Look Once: Unified, Real-Time Object Detection. In Proceedings of the IEEE Conference on Computer Vision and Pattern Recognition, Las Vegas, NV, USA, 27–30 June 2016; pp. 779–788.
11. Redmon, J.; Farhadi, A. YOLO9000: Better, Faster, Stronger. In Proceedings of the IEEE Conference on Computer Vision and Pattern Recognition, Honolulu, HI, USA, 21–26 July 2017; pp. 7263–7271.
12. Liu, W.; Anguelov, D.; Erhan, D.; Szegedy, C.; Reed, S.; Fu, C.Y.; Berg, A.C. SSD: Single Shot Multibox Detector. In European Conference on Computer Vision; Springer: Cham, Switzerland, 2016; pp. 21–37.
13. Sa, I.; Ge, Z.; Dayoub, F.; Upcroft, B.; Perez, T.; McCool, C. Deepfruits: A Fruit Detection System Using Deep Neural Networks. Sensors 2016, 16, 1222. [CrossRef] (http://doi.org/10.3390/s16081222) [PubMed] (http://www.ncbi.nlm.nih.gov/pubmed/27527168)
14. Tian, Y.; Yang, G.; Wang, Z.; Wang, H.; Li, E.; Liang, Z. Apple Detection during Different Growth Stages in Orchards Using the Improved YOLO-V3 Model. Comput. Electron. Agric. 2019, 157, 417–426. [CrossRef] (http://doi.org/10.1016/j.compag.2019.01.012)
15. Chen, S.W.; Shivakumar, S.S.; Dcunha, S.; Das, J.; Okon, E.; Qu, C.; Kumar, V. Counting Apples and Oranges with Deep Learning: A Data-Driven Approach. IEEE Robot. Autom. Lett. 2017, 2, 781–788. [CrossRef] (http://doi.org/10.1109/LRA.2017.2651944)
16. Koirala, A.; Walsh, K.B.; Wang, Z.; McCarthy, C. Deep Learning-Method Overview and Review of Use for Fruit Detection and Yield Estimation. Comput. Electron. Agric. 2019, 162, 219–234. [CrossRef] (http://doi.org/10.1016/j.compag.2019.04.017)
17. Huszár, V.D.; Adhikarla, V.K. Live Spoofing Detection for Automatic Human Activity Recognition Applications. Sensors 2021, 21, 7339. [CrossRef] (http://doi.org/10.3390/s21217339) [PubMed] (http://www.ncbi.nlm.nih.gov/pubmed/34770646)
18. Machado, M.A.; Rosado, L.S.; Mendes, N.M.; Miranda, R.M.; Santos, T.G. Multisensor Inspection of Laser-Brazed Joints in the Automotive Industry. Sensors 2021, 21, 7335. [CrossRef] (http://doi.org/10.3390/s21217335) [PubMed] (http://www.ncbi.nlm.nih.gov/pubmed/34770642)
19. Fan, X.; Zhou, J.; Xu, Y. Research Progress of UAV Low Altitude Remote Sensing Monitoring Agricultural Information. J. Xinjiang Univ. (Nat. Sci. Ed.) 2021, 38, 623–631.
20. Liu, S.B.; Yang, G.J.; Zhou, C.Q.; Jing, H.T.; Feng, H.K.; Xu, B.; Yang, H. Information Extraction of Maize Seedling Number Based on UAV Remote Sensing Image. J. Agric. Eng. 2018, 34, 69–77.
21. Wang, Y.; Yu, P. A Fast Intrusion Detection Method for High-Speed Railway Clearance Based on Low-Cost Embedded GPUs. Sensors 2021, 21, 7279. [CrossRef] (http://doi.org/10.3390/s21217279) [PubMed] (http://www.ncbi.nlm.nih.gov/pubmed/34770584)
22. Lapegna, M.; Balzano, W.; Meyer, N.; Romano, D. Clustering Algorithms on Low-Power and High-Performance Devices for Edge Computing Environment. Sensors 2021, 21, 5395. [CrossRef] (http://doi.org/10.3390/s21165395) [PubMed] (http://www.ncbi.nlm.nih.gov/pubmed/34450837)
23. Panero Martinez, R.; Schiopu, I.; Cornelis, B.; Munteanu, A. Real-Time Instance Segmentation of Traffic Videos for Embedded Devices. Sensors 2021, 21, 275. [CrossRef] (http://doi.org/10.3390/s21010275) [PubMed] (http://www.ncbi.nlm.nih.gov/pubmed/33401627)
24. Mazzia, V.; Khaliq, A.; Salvetti, F.; Chiaberge, M. Real-Time Apple Detection System Using Embedded Systems with Hardware Accelerators: An Edge AI Application. IEEE Access 2020, 8, 9102–9114. [CrossRef] (http://doi.org/10.1109/ACCESS.2020.2964608)

25. Sa, I.; Chen, Z.; Popovi´c, M.; Khanna, R.; Liebisch, F.; Nieto, J.; Siegwart, R. Weednet: Dense Semantic Weed Classification Using Multispectral Images and Mav for Smart Farming. IEEE Robot. Autom. Lett. 2017, 3, 588–595. [CrossRef] (http://doi.org/10.1109/LRA.2017.2774979)
26. Woo, S.; Park, J.; Lee, J.Y.; Kweon, I.S. CBAM: Convolutional Block Attention Module. In Proceedings of the European Conference on Computer Vision (ECCV), Munich, Germany, 8–14 September 2018; pp. 3–19.
27. Liu, S.; Huang, D.; Wang, Y. Learning Spatial Fusion for Single-Shot Object Detection. arXiv 2019, arXiv:1911.09516.

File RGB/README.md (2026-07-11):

# Sistema de Clasificación de Mandarinas — Prototipo RGB

## Descripción general

Esta carpeta contiene el prototipo inicial del sistema de clasificación automática de mandarinas, construido sobre una cámara RGB estándar (sin componente hiperespectral). Integra detección de objetos con YOLOv5, clasificación de calidad con una red neuronal en TensorFlow, y control de actuadores físicos mediante Arduino.

## Objetivo

Este prototipo tuvo como propósito validar, en una etapa temprana del proyecto, la viabilidad de un sistema de clasificación automática de mandarinas basado en visión por computador, clasificación de calidad y actuación física sobre una banda transportadora. Sirvió como base conceptual y experimental para el desarrollo posterior del sistema.

> **Estado:** este subsistema es una etapa exploratoria y anterior del proyecto. El desarrollo activo actual se encuentra en `SWIR/Pushbroom/`, que corresponde a la evolución posterior del proyecto hacia una cámara hiperespectral SWIR pushbroom. El contenido de esta carpeta no recibe mantenimiento continuo.

## Arquitectura del prototipo

El sistema se compone de tres bloques funcionales:

- **Detección** — localización de mandarinas en la imagen mediante YOLOv5.
- **Clasificación** — evaluación de calidad (buena / mala) mediante una red neuronal convolucional entrenada en TensorFlow, a partir de la región detectada.
- **Actuación** — comunicación con un Arduino que acciona servomotores para desviar la fruta según el resultado de la clasificación.

## Evolución del desarrollo

El desarrollo avanzó en tres fases de integración progresiva:

1. **Procesamiento con YOLO** — captura de imagen y detección de mandarinas, sin clasificación ni actuación.
2. **YOLO + red de clasificación** — se incorpora el recorte automático de la región detectada y la clasificación de calidad.
3. **YOLO + red + Arduino** — integración completa: detección, clasificación y activación física de los servomotores según el resultado. Esta fase constituye la base funcional del sistema en tiempo real, previa a optimizaciones finales.

## Estructura del repositorio

- **`Bibliografia/`** — artículos científicos que sustentan el marco teórico del proyecto (clasificación de frutas, visión por computador, uniformidad de color).
- **`Codigos arduino/`** — implementación del control de actuadores en el microcontrolador.
- **`Codigos_de_python_merge/`** — scripts en Python correspondientes a las fases de integración descritas arriba.
- **`Plan y poster/`** — documentación académica del trabajo de grado (plan de trabajo, informe de registro de tema y póster de presentación).
- **`Pruebas_Obtenidas/`** — evidencia visual de las pruebas realizadas sobre el sistema.
- **`codigos_auxiliares/`** — scripts de preprocesamiento de imágenes utilizados como apoyo antes del entrenamiento de la red.
- **`Red cnn/`** — desarrollo del modelo de red neuronal convolucional de clasificación.

## Tecnologías utilizadas

- Python
- TensorFlow
- YOLOv5
- Arduino

No existe en `RGB/` un archivo de dependencias (`requirements.txt` u otro) ni instrucciones de instalación/ejecución, a diferencia de `SWIR/Pushbroom/`, que sí cuenta con esa documentación. Para ejecutar los scripts de este prototipo es necesario revisar directamente su código fuente.

## Notas

- `RGB/` no representa el estado actual del sistema; para el desarrollo vigente consultar `SWIR/Pushbroom/`.

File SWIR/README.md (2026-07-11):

# SWIR

Punto de entrada al subsistema SWIR del proyecto: la implementación actual y activa del sistema de clasificación automática de mandarinas, basada en una cámara hiperespectral SWIR (infrarrojo de onda corta) de tipo *pushbroom*.

## Propósito

Esta carpeta agrupa todo el trabajo correspondiente al enfoque hiperespectral del proyecto: el sistema ejecutable, los análisis offline que sustentan sus parámetros de configuración, y la evidencia de pruebas realizadas sobre el sistema en banco.

## Estructura

SWIR/ se organiza en tres subcarpetas con roles distintos y complementarios:

### `Pushbroom/`

Contiene el **sistema ejecutable**: la implementación completa del pipeline de captura, detección, clasificación y actuación que corre en tiempo real sobre la banda transportadora. Es el subsistema en desarrollo activo del proyecto. Su arquitectura interna, configuración y modo de ejecución están documentados en `Pushbroom/README.md`.

### `Analisis_Bandas_de_soporte/`

Contiene los scripts de análisis offline utilizados para determinar los parámetros espectrales que `Pushbroom/` usa en producción, en particular los offsets de canal (`OFFSETS_STACK`) respecto a la banda pico. Este análisis se hizo una sola vez, de forma previa e independiente a la ejecución en tiempo real, y sus resultados quedaron congelados en la configuración del sistema ejecutable.

### `Pruebas_del_sistema_02_06_26/`

Contiene evidencia (imágenes) de una sesión de pruebas del sistema realizada en una fecha específica. Corresponde a un registro histórico de una corrida de pruebas, no a código ni a documentación funcional.

## Relación entre las carpetas

`Analisis_Bandas_de_soporte/` alimenta con parámetros a `Pushbroom/` (de forma offline, no en tiempo de ejecución); `Pushbroom/` es el sistema que efectivamente se ejecuta; y `Pruebas_del_sistema_02_06_26/` documenta evidencia de una ejecución puntual de ese sistema. No existe una dependencia en sentido inverso: `Pushbroom/` no depende de `Pruebas_del_sistema_02_06_26/` para funcionar.

Para el detalle del funcionamiento interno del pipeline (módulos, hilos, flujo de datos), consultar `Pushbroom/README.md`.

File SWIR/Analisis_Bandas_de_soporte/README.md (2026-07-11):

# Analisis_Bandas_de_soporte

## Objetivo del análisis espectral

Esta carpeta contiene el análisis espectral offline utilizado para determinar qué canales (bandas) de la cámara hiperespectral SWIR aportan mayor capacidad de separar las clases de calidad de la fruta. El resultado de este análisis es el conjunto de offsets de canal respecto a la banda pico (`OFFSETS_STACK`) que el sistema `Pushbroom/` utiliza en producción.

## Scripts principales

### `extraer_features_espectrales.py`

Calcula estadísticas espectrales por cubo hiperespectral, restringidas a los píxeles de la máscara segmentada de la fruta (no a un ROI rectangular ni al cubo completo), evaluando un barrido de offsets candidatos respecto a la banda pico.

### `analizar_separabilidad.py`

Toma las estadísticas generadas en el paso anterior y ordena (rankea) los offsets candidatos según su capacidad de separar las clases de calidad, produciendo una recomendación de los offsets a utilizar.

## Fuentes de verdad (JSON de entrada)

El análisis depende de dos archivos JSON que deben mantenerse consistentes entre sí:

- **`reporte_picos.json`** — fuente primaria: identifica cada cubo (`cube_id`), su banda pico y su ruta.
- **`cube_index.json`** — fuente secundaria: mapea cada `cube_id` a su lote (`lot_id`).

## Resultados generados

Los scripts producen sus salidas en la subcarpeta `analisis_bandas/`, en forma de archivos JSON (con las estadísticas espectrales extraídas y el ranking/recomendación de offsets) y una visualización de apoyo del análisis de separabilidad.

## Relación con Pushbroom

Los offsets recomendados por este análisis son los que quedan congelados en `OFFSETS_STACK` dentro de la configuración del sistema ejecutable (`SWIR/Pushbroom/`). Esta carpeta no es consultada ni ejecutada por `Pushbroom/` en tiempo de ejecución: su resultado se traslada manualmente a la configuración del sistema. Cambiar estos offsets implica reentrenar los modelos de detección y clasificación que dependen de ellos.

## Carácter del análisis

Todo el contenido de esta carpeta es **offline**: se ejecuta de forma independiente y previa, como insumo para fijar parámetros de configuración. No forma parte del pipeline en tiempo real de captura, detección, clasificación y actuación.

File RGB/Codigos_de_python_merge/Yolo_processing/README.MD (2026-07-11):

Carpeta de Pruebas del Sistema
En esta carpeta se encuentran los distintos códigos desarrollados durante la fase de pruebas e integración del sistema completo.

Aquí se incluyen scripts utilizados para:

Aprender a abrir y gestionar la cámara desde Python.

Validar la captura de imágenes con OpenCV.

Integrar YOLOv5 para detección de mandarinas.

Conectar la red de clasificación en TensorFlow.

Realizar pruebas conjuntas entre cámara, detección y clasificación.

Progresión de Desarrollo
Los archivos reflejan la evolución del sistema, desde pruebas básicas e independientes hasta la integración parcial de todos los componentes.

Las etapas incluyen:

Captura de imagen funcional.

Detección correcta con YOLOv5.

Recorte automático mediante coordenadas.

Envío de la imagen recortada a la red de clasificación.

Visualización de resultados en tiempo real.

Versión Más Estable de Esta Etapa
Los últimos códigos desarrollados en esta fase, donde:

La cámara funciona correctamente.

YOLO detecta las mandarinas de forma estable.

La red clasifica adecuadamente.

El sistema opera de manera conjunta y coherente.

corresponden a los archivos:

Código
￼
C_final_...
Estos representan el cierre de la etapa de pruebas antes de avanzar hacia la integración completa con el sistema mecánico y el control mediante Arduino.

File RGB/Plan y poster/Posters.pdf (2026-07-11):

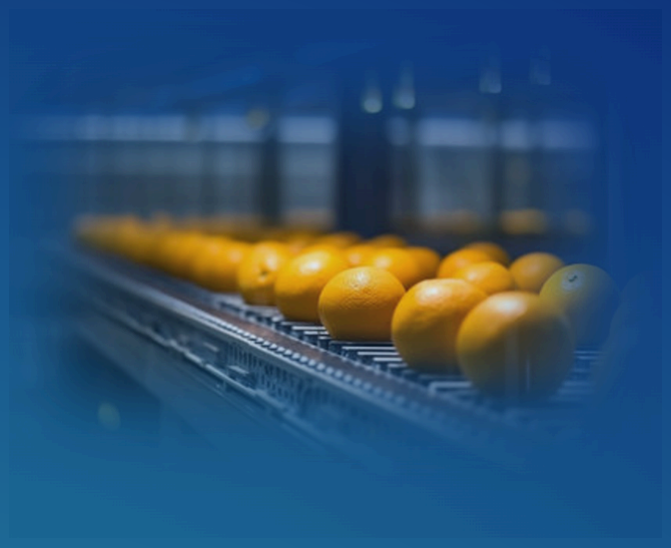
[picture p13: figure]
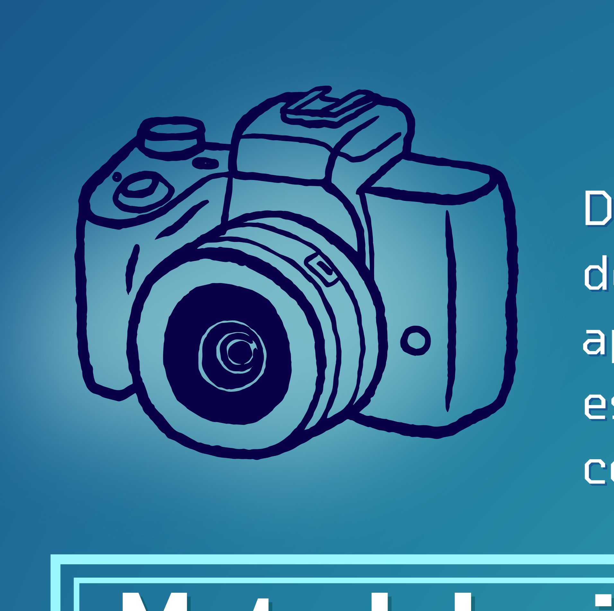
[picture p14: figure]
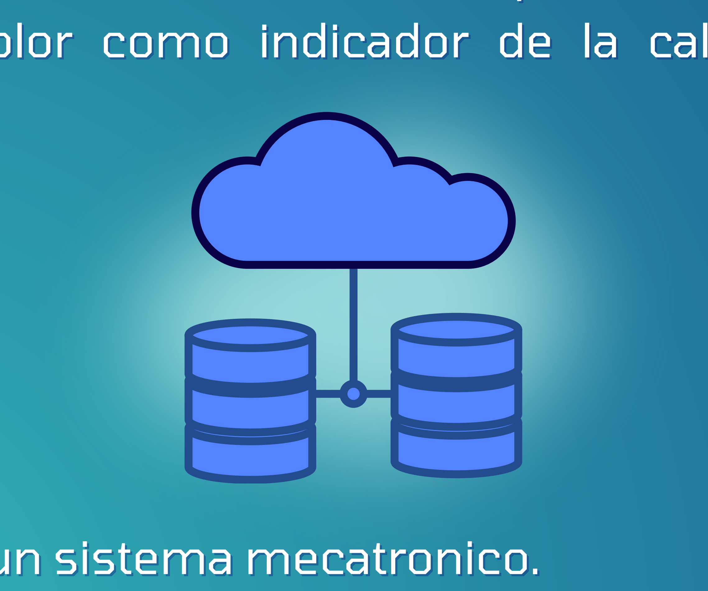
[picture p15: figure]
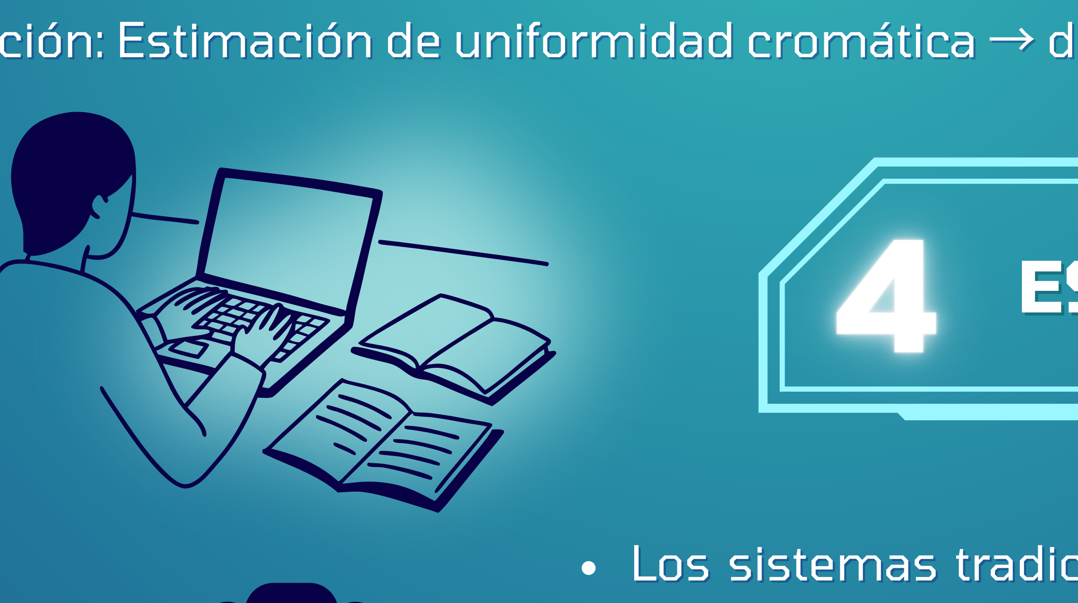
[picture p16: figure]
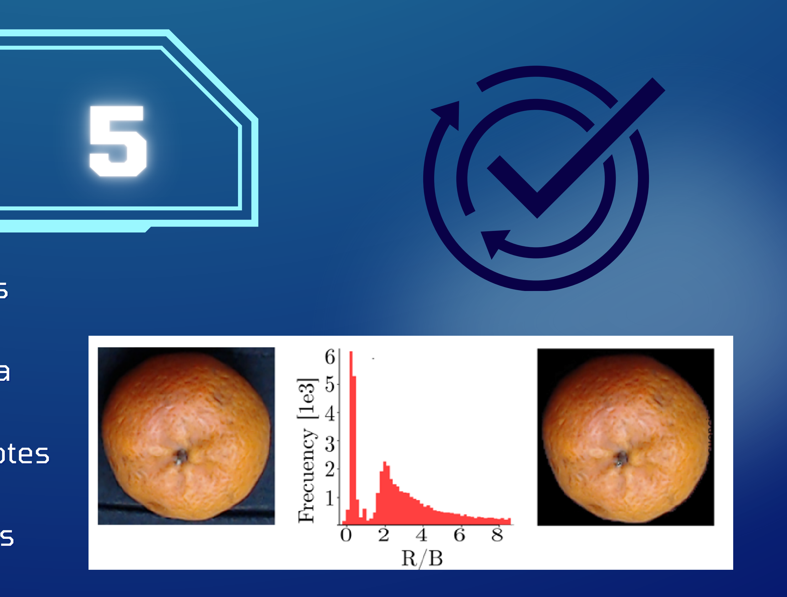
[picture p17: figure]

johan2215588@correo.uis.edu.co meyer2211601@correo.uis.edu.co

Modulo mecatronico: Diseño e implementacion de un sistema mecatronico. Adquisición de datos: Captura de imágenes espectrales en banda transportadora. Preprocesamiento: Normalización, segmentación y extracción de características. Modelo de Deep Learning: Implementación de red neuronal entrenada con índices de color.
Clasificación: Estimación de uniformidad cromática → decisión “Apto” o “No apto”.

Modulo mecatronico: Diseño e implementacion de un sistema mecatronico. Adquisición de datos: Captura de imágenes espectrales en banda transportadora. Preprocesamiento: Normalización, segmentación y extracción de características. Modelo de Deep Learning: Implementación de red neuronal entrenada con índices de color.
Clasificación: Estimación de uniformidad cromática → decisión “Apto” o “No apto”.

# IINNTTRROODDUUCCCCIIOONN

La uniformidad de color es un indicador clave de madurez y defectos superficiales.
Los sistemas industriales actuales priorizan peso y tamaño, pero no siempre consideran color.
La combinación de visión por computador + aprendizaje profundo permite una evaluación objetiva y reproducible.

La uniformidad de color es un indicador clave de madurez y defectos superficiales.
Los sistemas industriales actuales priorizan peso y tamaño, pero no siempre consideran color.
La combinación de visión por computador + aprendizaje profundo permite una evaluación objetiva y reproducible.

# OBJETIVO GENERAL

# OBJETIVO GENERAL

Diseñar e implementar un sistema automatizado de clasificación de frutos cítricos en banda transportadora, basado en una red de aprendizaje profundo que utilice información espectral para estimar la uniformidad de color como indicador de la calidad comercial de los frutos.

Diseñar e implementar un sistema automatizado de clasificación de frutos cítricos en banda transportadora, basado en una red de aprendizaje profundo que utilice información espectral para estimar la uniformidad de color como indicador de la calidad comercial de los frutos.

# Metodologia propuesta

# Metodologia propuesta

## ESTUDIOS PREVIOS

Los sistemas tradicionales se enfocan en peso y tamaño.
La visión por computador permite analizar color y madurez.
Las CNN mejoran la precisión y uniformidad en la clasificación.
La unión de IA y mecatrónica impulsa soluciones automatizadas para la agroindustria.

Los sistemas tradicionales se enfocan en peso y tamaño.
La visión por computador permite analizar color y madurez.
Las CNN mejoran la precisión y uniformidad en la clasificación.
La unión de IA y mecatrónica impulsa soluciones automatizadas para la agroindustria.

## RESULTADOS ESPERADOS

## RESULTADOS ESPERADOS

Clasificación en tiempo real de frutos cítricos.
Reducción de errores humanos en la selección.
Mejora en la homogeneidad de los lotes y la calidad comercial.
Sistema escalable hacia aplicaciones industriales de gran volumen.

Clasificación en tiempo real de frutos cítricos.
Reducción de errores humanos en la selección.
Mejora en la homogeneidad de los lotes y la calidad comercial.
Sistema escalable hacia aplicaciones industriales de gran volumen.

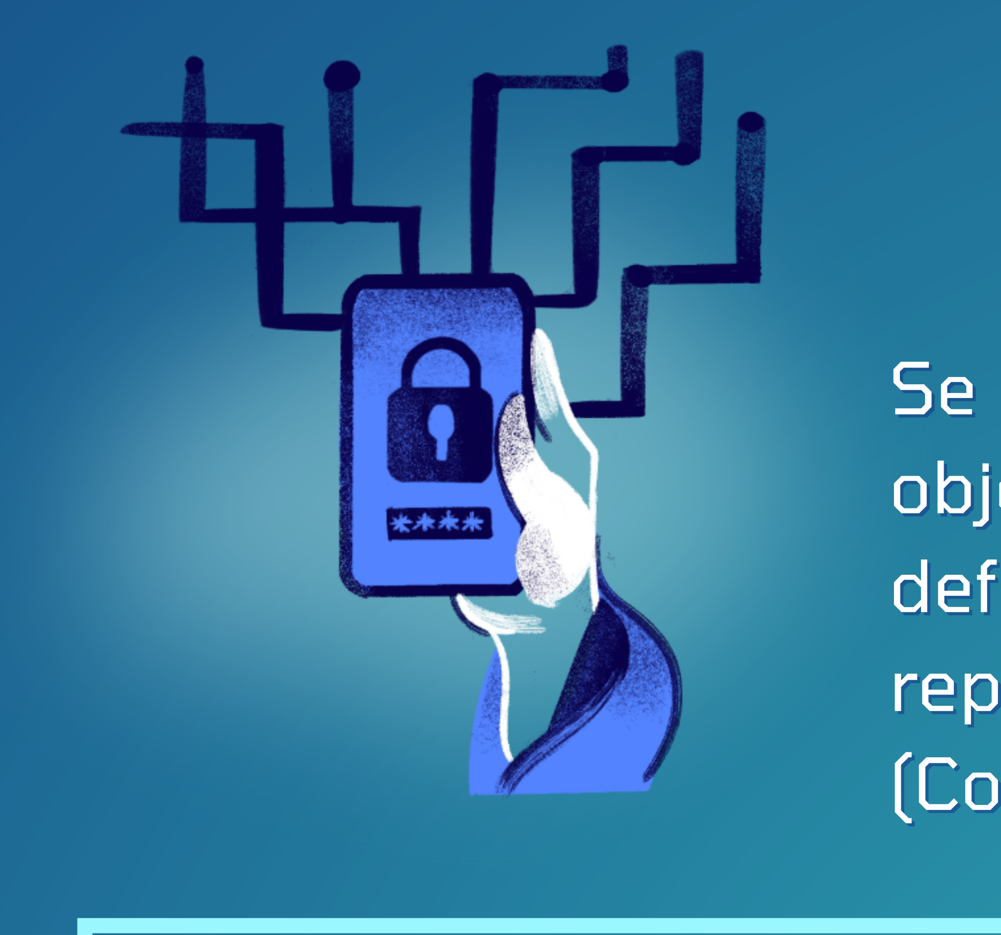
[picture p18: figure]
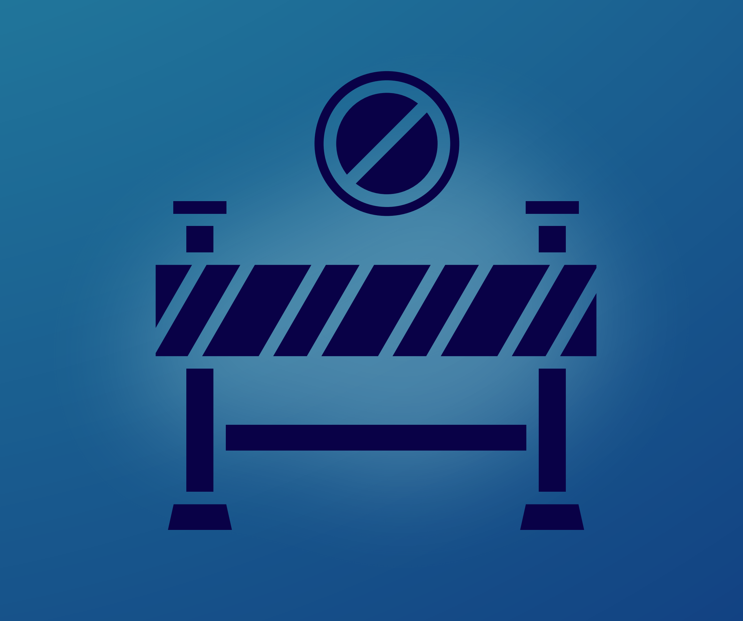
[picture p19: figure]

Presupuesto limitado y recursos de laboratorio compartidos.

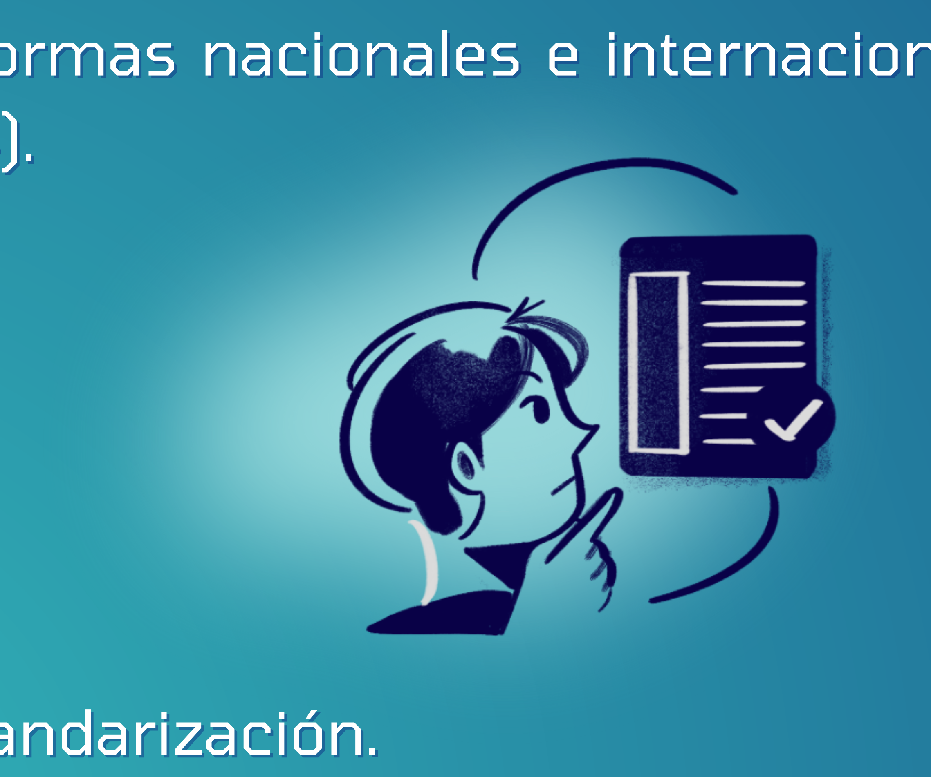
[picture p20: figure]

Disponibilidad reducida de cámaras hiperespectrales. Tiempo corto para diseño, implementación y pruebas.

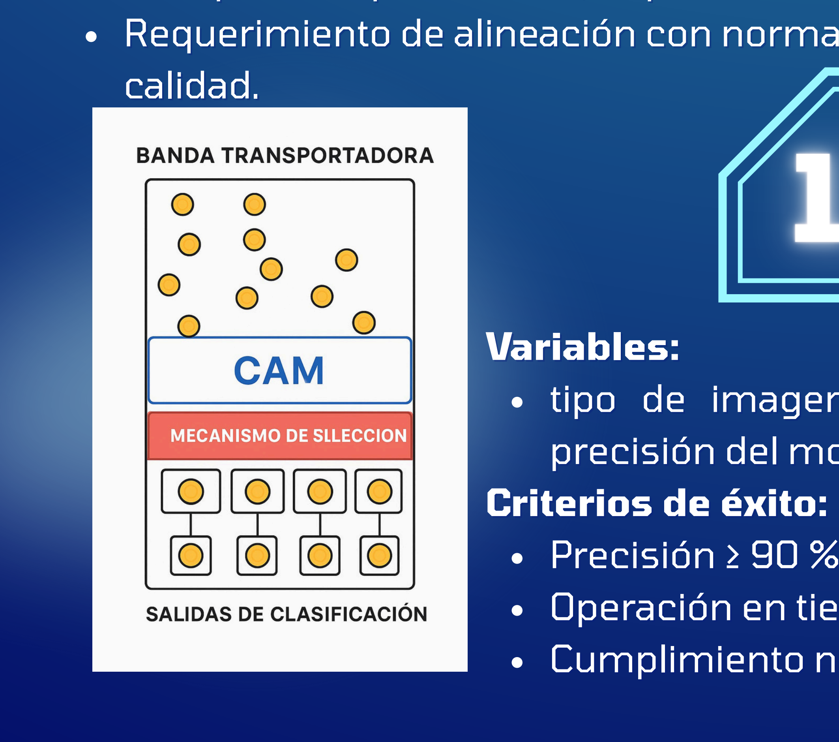
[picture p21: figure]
calidad.; Variables:; Criterios de éxito:

Requerimiento de alineación con normas técnicas de

Presupuesto limitado y recursos de laboratorio compartidos.
Disponibilidad reducida de cámaras hiperespectrales. Tiempo corto para diseño, implementación y pruebas. Requerimiento de alineación con normas técnicas de

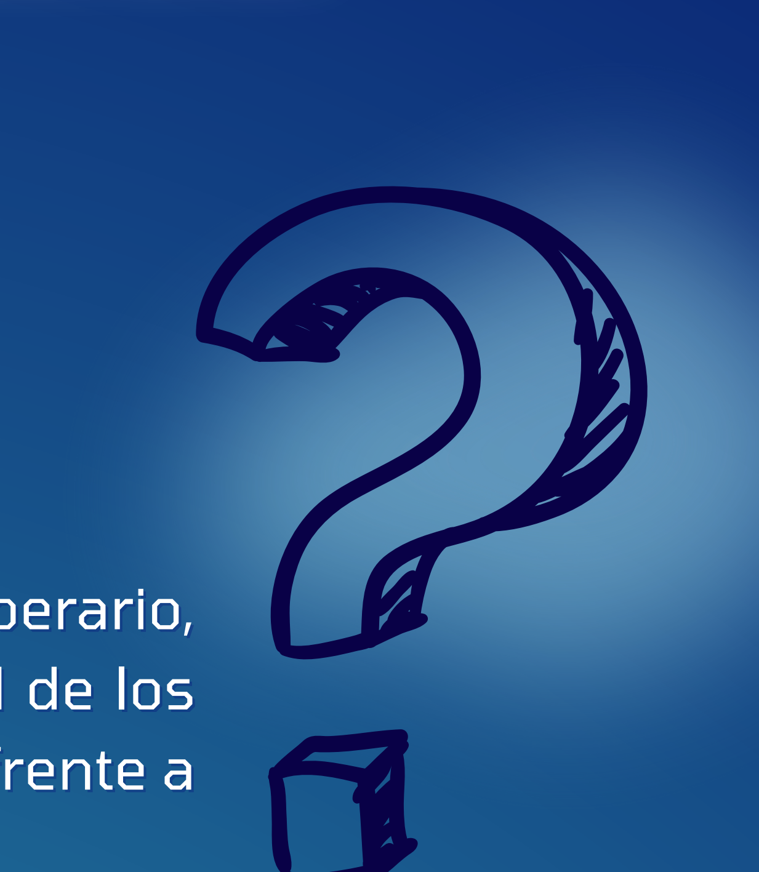
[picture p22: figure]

Errores en la selección y pérdida de producto comercializable.
Procesos poco eficientes y difícil trazabilidad.
Menor competitividad en exportación por falta de control de calidad. Dificultad para aplicar tecnologías modernas en el sector agrícola nacional.

Errores en la selección y pérdida de producto comercializable.
Procesos poco eficientes y difícil trazabilidad.
Menor competitividad en exportación por falta de control de calidad. Dificultad para aplicar tecnologías modernas en el sector agrícola nacional.

tipo de imagen (RGB / espectral), tamaño del dataset, precisión del modelo, velocidad de inferencia.

Precisión ≥ 90 % en clasificación de madurez y defectos. Operación en tiempo real en banda transportadora. Cumplimiento normativo y resultados reproducibles.

tipo de imagen (RGB / espectral), tamaño del dataset, precisión del modelo, velocidad de inferencia.

Precisión ≥ 90 % en clasificación de madurez y defectos. Operación en tiempo real en banda transportadora. Cumplimiento normativo y resultados reproducibles.

# PROBLEMA CENTRAL

# PROBLEMA CENTRAL

La clasificación manual de frutos cítricos depende del criterio del operario, lo que genera errores, lentitud y falta de uniformidad en la calidad de los lotes. Esta variabilidad afecta la competitividad de los productores frente a mercados que exigen estándares altos y procesos trazables.

La clasificación manual de frutos cítricos depende del criterio del operario, lo que genera errores, lentitud y falta de uniformidad en la calidad de los lotes. Esta variabilidad afecta la competitividad de los productores frente a mercados que exigen estándares altos y procesos trazables.

# NNEECCEESSIIDDAADD

Se requiere un sistema automatizado que evalúe de manera objetiva la uniformidad del color como indicador de madurez y defectos, garantizando una clasificación más confiable, reproducible y alineada con normas nacionales e internacionales (Codex Alimentarius, NTC 4084).

Se requiere un sistema automatizado que evalúe de manera objetiva la uniformidad del color como indicador de madurez y defectos, garantizando una clasificación más confiable, reproducible y alineada con normas nacionales e internacionales (Codex Alimentarius, NTC 4084).

# CCAAUUSSAASS

Dependencia de la inspección manual y falta de estandarización.
Escasa adopción de tecnologías basadas en visión por computador.
Costos altos de equipos comerciales para clasificación automática.
Falta de infraestructura experimental que integre IA y sistemas mecatrónicos.

Dependencia de la inspección manual y falta de estandarización.
Escasa adopción de tecnologías basadas en visión por computador.
Costos altos de equipos comerciales para clasificación automática.
Falta de infraestructura experimental que integre IA y sistemas mecatrónicos.

## CCOONNSSEECCUUEENNCCIIAASS

## RREESSTTRRIICCCCIIOONNEESS

## VARIABLES Y CRITERIOS DE EXITO

## VARIABLES Y CRITERIOS DE EXITO

Realistas:
Aplicar transfer learning con CNN (MobileNet, EfficientNet).

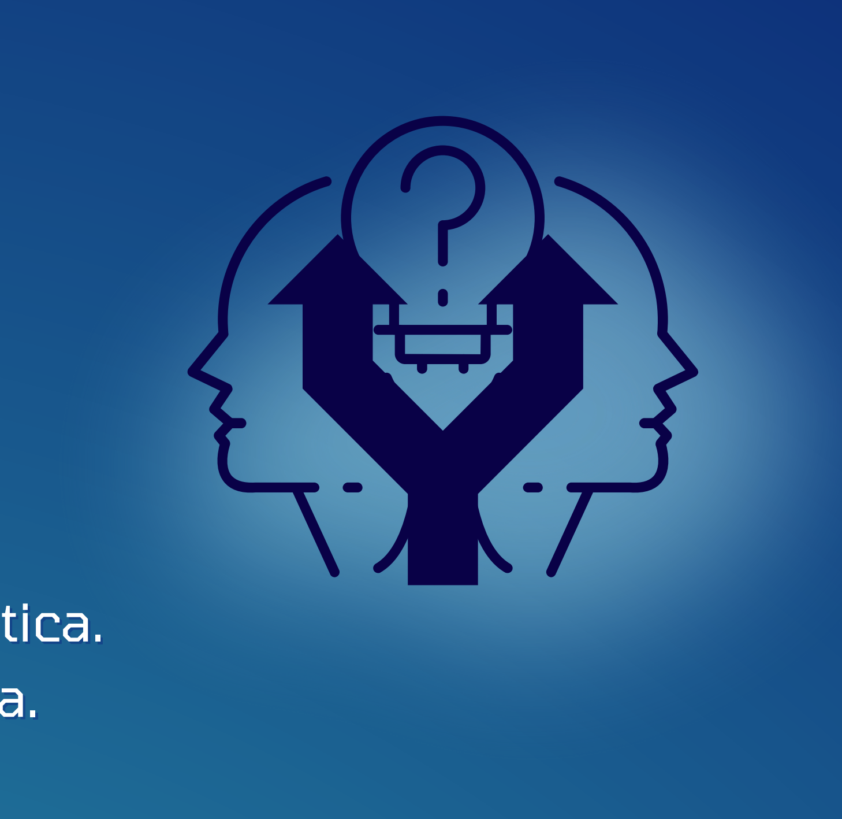
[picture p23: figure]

Calcular el Citrus Colour Index (CCI) como referencia cromática. Incorporar un módulo de separación automática en la banda. Disruptivas:
Generar datos sintéticos con IA generativa (GANs).
Usar sensores multimodales (RGB + térmico + espectral).
Implementar una red colaborativa de productores para mejorar el modelo.

Realistas:
Aplicar transfer learning con CNN (MobileNet, EfficientNet). Calcular el Citrus Colour Index (CCI) como referencia cromática. Incorporar un módulo de separación automática en la banda. Disruptivas:
Generar datos sintéticos con IA generativa (GANs).
Usar sensores multimodales (RGB + térmico + espectral).
Implementar una red colaborativa de productores para mejorar el modelo.

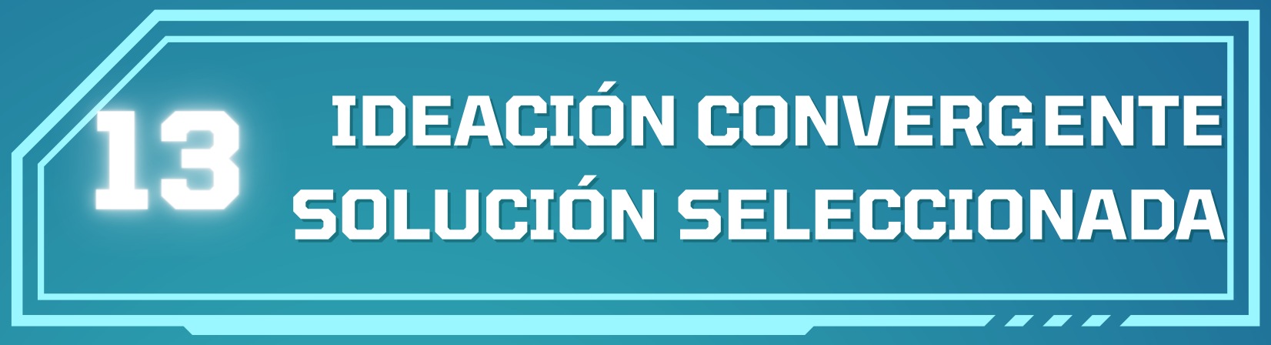
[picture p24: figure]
IDEACIÓN CONVERGENTE SOLUCIÓN SELECCIONADA

Se selecciona una solución realista e implementable:
Un sistema de clasificación basado en redes neuronales ligeras con transfer learning, entrenadas para estimar la uniformidad cromática de los cítricos.
El sistema se integrará a una banda transportadora modular, que captura imágenes, analiza color y activa el mecanismo de separación según el resultado del modelo.

Se selecciona una solución realista e implementable:
Un sistema de clasificación basado en redes neuronales ligeras con transfer learning, entrenadas para estimar la uniformidad cromática de los cítricos.
El sistema se integrará a una banda transportadora modular, que captura imágenes, analiza color y activa el mecanismo de separación según el resultado del modelo.

# IDEACIÓN DIVERGENTE

# IDEACIÓN DIVERGENTE

# RETOS DEL PROYECTO

# RETOS DEL PROYECTO

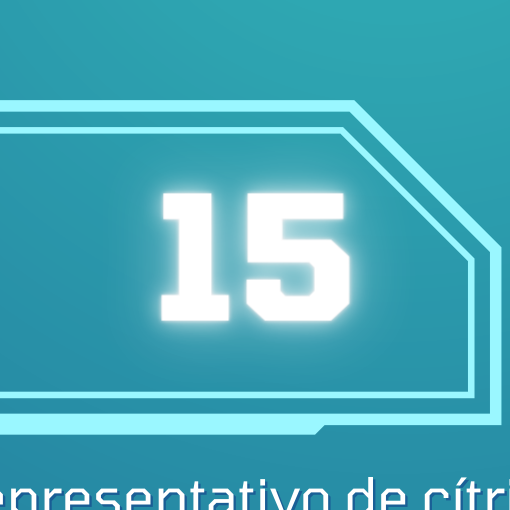
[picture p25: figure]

Construir un dataset local representativo de cítricos. Asegurar condiciones de iluminación estables.

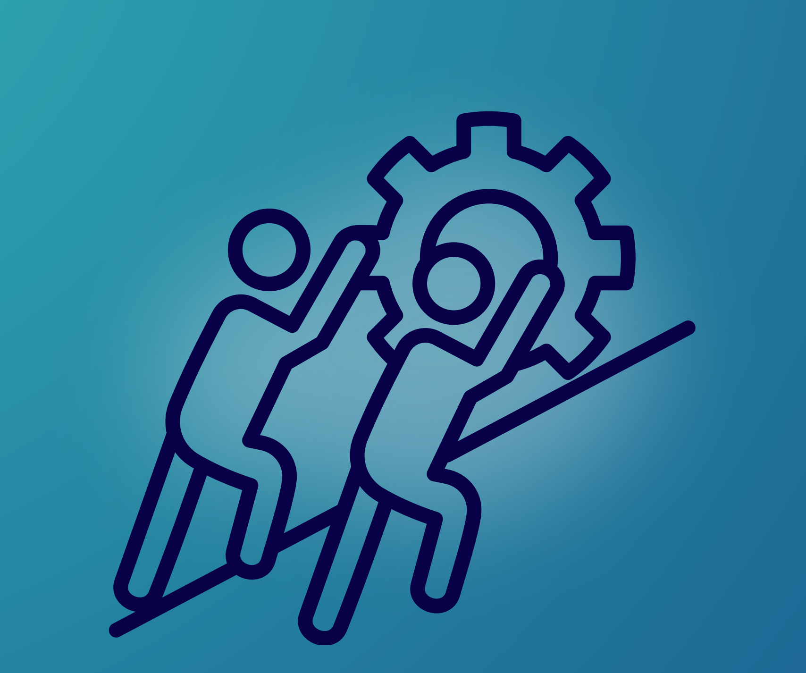
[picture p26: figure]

Integrar visión por computador, IA y control electrónico. Validar precisión y velocidad en pruebas reales.

Construir un dataset local representativo de cítricos. Asegurar condiciones de iluminación estables. Integrar visión por computador, IA y control electrónico. Validar precisión y velocidad en pruebas reales.


## OBJETIVOS ESPECIFICOS

## OBJETIVOS ESPECIFICOS


Diseñar e implementar el módulo mecatrónico de la banda transportadora. Entrenar una red neuronal que clasifique la uniformidad de color del fruto. Integrar el modelo con el sistema de control para clasificar en tiempo real. Evaluar el desempeño mediante métricas como accuracy y precision .

Diseñar e implementar el módulo mecatrónico de la banda transportadora. Entrenar una red neuronal que clasifique la uniformidad de color del fruto. Integrar el modelo con el sistema de control para clasificar en tiempo real. Evaluar el desempeño mediante métricas como accuracy y precision .

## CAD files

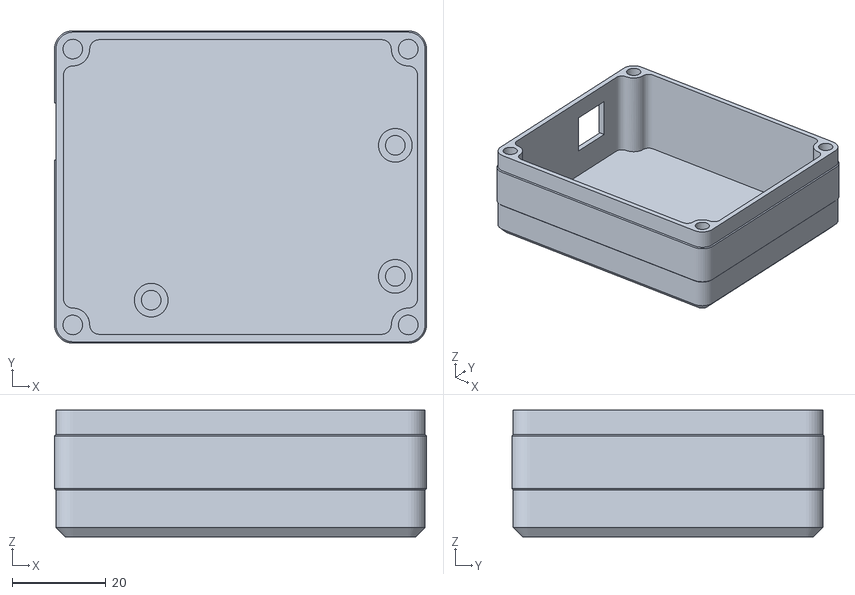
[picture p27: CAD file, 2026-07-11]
Impresiones_3D/box.stl
79.3 x 66.6 x 27.0

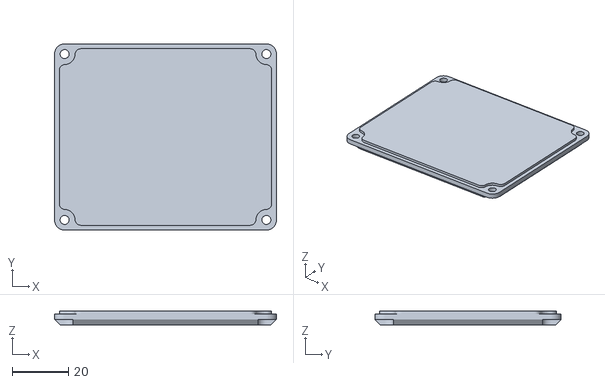
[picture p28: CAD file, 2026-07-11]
Impresiones_3D/top.stl
78.7 x 66.0 x 5.00

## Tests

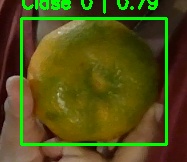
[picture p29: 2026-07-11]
RGB/Pruebas_Obtenidas/Image_processing/PAD_Dinamico/mandarina_7_MALA.jpg

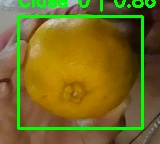
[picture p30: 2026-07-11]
RGB/Pruebas_Obtenidas/Image_processing/PAD_Dinamico/mandarina_9_MALA.jpg

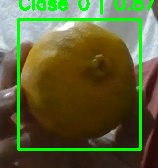
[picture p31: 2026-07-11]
RGB/Pruebas_Obtenidas/Image_processing/PAD_Dinamico/mandarina_2_MALA.jpg

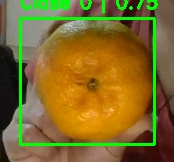
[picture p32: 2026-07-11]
RGB/Pruebas_Obtenidas/Image_processing/PAD_Dinamico/mandarina_5_MALA.jpg

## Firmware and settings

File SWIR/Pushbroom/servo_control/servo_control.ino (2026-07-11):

// =============================================================================
// servo_control.ino — Ejecutor inmediato de servos con máquina de estados
// =============================================================================
// Hardware:
//   - Arduino UNO
//   - 2 servomotores en pines PWM D9 (izquierdo) y D6 (derecho)
//   - Alimentación de servos desde fuente externa 5V/3-5A con GND común
//
// Protocolo serial recibido desde Python:
//   "L\n" → accionar servo carril izquierdo (D9)
//   "R\n" → accionar servo carril derecho  (D6)
//
// Arduino NO gestiona delays largos ni colas.
// Todo el timing de tránsito vive en actuator.py (Python).
//
// Máquina de estados por servo:
//   CERRADO → recibe comando → ABRIENDO → millis() >= t_cierre → CERRANDO → CERRADO
//   Mientras el servo está abierto, el loop sigue corriendo y puede
//   recibir comandos del otro carril sin bloqueos.
//
// Notas:
//   SERVO_LEFT_PIN y SERVO_RIGHT_PIN son configuración de hardware.
//   Si cambian los pines físicos, modificar únicamente esas constantes.
// =============================================================================

#include <Servo.h>

// =============================================================================
// CONFIGURACIÓN
// =============================================================================

#define SERVO_LEFT_PIN   9    // D9 → servo carril izquierdo
#define SERVO_RIGHT_PIN  6    // D6 → servo carril derecho

#define ANGULO_CERRADO_L   13
#define ANGULO_ABIERTO_L  100

#define ANGULO_CERRADO_R   12
#define ANGULO_ABIERTO_R  100

#define TIEMPO_ABIERTO_MS  400   // ms que la compuerta permanece abierta

#define BAUDRATE  115200

// =============================================================================
// ESTADOS
// =============================================================================

enum EstadoServo { CERRADO, ABIERTO };

struct CanalServo {
  Servo        servo;
  EstadoServo  estado;
  unsigned long t_cierre;   // millis() en que debe cerrarse
  int          ang_abierto;
  int          ang_cerrado;
  char         id;
};

CanalServo canales[2];

// =============================================================================
// BUFFER SERIAL
// =============================================================================

char serial_buffer[16];
int  serial_idx = 0;

// =============================================================================
// SETUP
// =============================================================================

void setup() {
  Serial.begin(BAUDRATE);

  // Carril izquierdo (L)
  canales[0].servo.attach(SERVO_LEFT_PIN);
  canales[0].estado     = CERRADO;
  canales[0].t_cierre   = 0;
  canales[0].ang_abierto  = ANGULO_ABIERTO_L;
  canales[0].ang_cerrado  = ANGULO_CERRADO_L;
  canales[0].id           = 'L';
  canales[0].servo.write(ANGULO_CERRADO_L);

  // Carril derecho (R)
  canales[1].servo.attach(SERVO_RIGHT_PIN);
  canales[1].estado     = CERRADO;
  canales[1].t_cierre   = 0;
  canales[1].ang_abierto  = ANGULO_ABIERTO_R;
  canales[1].ang_cerrado  = ANGULO_CERRADO_R;
  canales[1].id           = 'R';
  canales[1].servo.write(ANGULO_CERRADO_R);

  delay(300);
  Serial.println("READY");
}

// =============================================================================
// LOOP PRINCIPAL — no bloqueante
// =============================================================================

void loop() {
  leer_serial();
  actualizar_servos();
}

// =============================================================================
// LECTURA SERIAL NO BLOQUEANTE
// =============================================================================

void leer_serial() {
  while (Serial.available() > 0) {
    char c = Serial.read();
    if (c == '\n') {
      serial_buffer[serial_idx] = '\0';
      parsear_comando(serial_buffer);
      serial_idx = 0;
    } else if (serial_idx < 15) {
      serial_buffer[serial_idx++] = c;
    }
  }
}

// =============================================================================
// PARSING
// =============================================================================

void parsear_comando(char* cmd) {
  if (strlen(cmd) == 0) return;

  if (strcmp(cmd, "L") == 0) {
    abrir_canal(0);
  } else if (strcmp(cmd, "R") == 0) {
    abrir_canal(1);
  } else {
    Serial.print("ERR:cmd_desconocido:");
    Serial.println(cmd);
  }
}

void abrir_canal(int idx) {
  CanalServo& c = canales[idx];
  c.servo.write(c.ang_abierto);
  c.estado   = ABIERTO;
  c.t_cierre = millis() + TIEMPO_ABIERTO_MS;
  Serial.print("FIRE:");
  Serial.println(c.id);
}

// =============================================================================
// MÁQUINA DE ESTADOS — se llama cada iteración del loop
// =============================================================================

void actualizar_servos() {
  unsigned long ahora = millis();
  for (int i = 0; i < 2; i++) {
    CanalServo& c = canales[i];
    if (c.estado == ABIERTO && ahora >= c.t_cierre) {
      c.servo.write(c.ang_cerrado);
      c.estado = CERRADO;
      Serial.print("CLOSE:");
      Serial.println(c.id);
    }
  }
}

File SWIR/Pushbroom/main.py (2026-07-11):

# =============================================================================
# main.py — Orquestador principal del sistema de clasificación SWIR
# =============================================================================
import threading
import time
import queue
import cv2
import numpy as np
from collections import deque
from typing import Optional

import config
from camera import crear_camara, CamaraBase
from buffer import RollingBuffer
from pseudo_rgb import construir_pseudo_rgb, pseudo_rgb_para_display
from detector import DetectorYOLO
from tracker import Tracker
from classifier import Clasificador
from actuator import GestorActuadores
from preprocessing import preprocess_channels

# =============================================================================
YOLO_CADA_N_LINEAS: int = 15

ids_en_clasificacion: set = set()
lock_ids_cnn = threading.Lock()


# =============================================================================
# HILO CLASIFICADOR
# =============================================================================

def worker_clasificador(
    cola_entrada: queue.Queue,
    cola_salida: queue.Queue,
    buffer: RollingBuffer,
    clasificador: Clasificador
) -> None:
    while True:
        try:
            trabajo = cola_entrada.get(timeout=0.5)
        except queue.Empty:
            continue

        if trabajo is None:
            break

        id_obj, obj, linea_inicio_snap = trabajo

        try:
            # ── Extraer ROI crudo del buffer ──────────────────────────
            roi_crudo = buffer.extraer_roi_espectral(
                bbox_x1=obj.x1,
                bbox_x2=obj.x2,
                bbox_y1=obj.y1,
                bbox_y2=obj.y2,
                linea_inicio_frame=linea_inicio_snap
            )

            if roi_crudo is None or roi_crudo.size == 0:
                if config.LOG_LEVEL >= 1:
                    print(f"[CNN] ID={id_obj}: ROI inválido o expirado.")
                with lock_ids_cnn:
                    ids_en_clasificacion.discard(id_obj)
                continue

            # ── Preprocesamiento Vy (norm por canal + gamma) ──────────
            # Aplicado UNA SOLA VEZ — identical al entrenamiento
            canales = [roi_crudo[:, :, b] for b in range(roi_crudo.shape[2])]
            roi_procesado = preprocess_channels(canales)
            # roi_procesado: (H, W, N_BANDS) float32 en [0,1]

            # ── Clasificar ────────────────────────────────────────────
            resultado = clasificador.predecir(roi_procesado)

            # ── Encolar resultado ─────────────────────────────────────
            cola_salida.put({
                "id_obj"      : id_obj,
                "carril"      : obj.carril,
                "etiqueta"    : "BUENA" if resultado.es_buena else "MALA",
                "score"       : resultado.probabilidad,
                "tiempo_cruce": time.time()
            })

            if config.LOG_LEVEL >= 1:
                print(f"[CNN] ID={id_obj} carril={obj.carril} → "
                      f"{'BUENA' if resultado.es_buena else 'MALA'} "
                      f"score={resultado.probabilidad:.3f}")

        except Exception as e:
            print(f"[CNN] Error clasificando ID={id_obj}: {e}")
        finally:
            with lock_ids_cnn:
                ids_en_clasificacion.discard(id_obj)


# =============================================================================
# VISUALIZACIÓN
# =============================================================================

# Colores BGR para cv2
COLOR_VERDE    = (0, 200, 0)
COLOR_ROJO     = (0, 60, 220)
COLOR_AMARILLO = (0, 180, 255)
COLOR_CYAN     = (255, 200, 0)
COLOR_GRIS     = (160, 160, 160)
COLOR_BLANCO   = (255, 255, 255)
COLOR_NEGRO    = (0, 0, 0)
COLOR_PANEL    = (30, 30, 30)
COLOR_LINEA_SEP= (70, 70, 70)


def construir_canvas(
    pseudo_rgb:      np.ndarray,
    objetos_activos: dict,
    ultima_clasif:   Optional[dict],
    contadores:      dict,
    fps_yolo:        float,
    fps_camara:      float,
    estado_modulos:  dict,
    linea_virtual_x: int,
    escala_x:        float,
    x_off:           int,
    y_off:           int,
    img_panel_h:     int
) -> np.ndarray:
    """
    Construye el canvas completo de la ventana fija.

    Panel izquierdo: pseudo-RGB con overlays.
    Panel derecho: estado, contadores, módulos, config.
    """
    W  = config.WINDOW_WIDTH
    H  = config.WINDOW_HEIGHT
    RP = config.RIGHT_PANEL_WIDTH
    LP = W - RP  # ancho panel izquierdo

    canvas = np.full((H, W, 3), COLOR_PANEL, dtype=np.uint8)

    # ── Panel izquierdo — pseudo-RGB ──────────────────────────────────
    # pseudo_rgb ya viene en BGR (convertido antes de llamar aquí)
    panel_img = pseudo_rgb  # (img_panel_h, LP, 3)
    if panel_img.shape[0] <= H and panel_img.shape[1] <= LP:
        canvas[:panel_img.shape[0], :panel_img.shape[1]] = panel_img

    # Línea de clasificación virtual
    lx = x_off + int(linea_virtual_x * escala_x)
    cv2.line(canvas, (lx, 0), (lx, H), (255, 120, 0), 2)

    # Línea separación de carriles
    mitad_y = y_off + img_panel_h // 2
    cv2.line(canvas, (0, mitad_y), (LP, mitad_y), COLOR_GRIS, 1)
    cv2.putText(canvas, "Carril 2", (8, mitad_y - 6),
                cv2.FONT_HERSHEY_SIMPLEX, 0.38, (180, 180, 255), 1)
    cv2.putText(canvas, "Carril 1", (8, mitad_y + 14),
                cv2.FONT_HERSHEY_SIMPLEX, 0.38, (180, 180, 255), 1)

    # Objetos trackeados con bboxes
    for id_obj, obj in objetos_activos.items():
        bx1 = x_off + int(obj.x1 * escala_x)
        bx2 = x_off + int(obj.x2 * escala_x)
        by1 = y_off + obj.y1
        by2 = y_off + obj.y2
        bcx = x_off + int(obj.cx * escala_x)
        bcy = y_off + obj.cy

        if obj.clasificado:
            es_buena = getattr(obj, 'es_buena', None)
            color = COLOR_VERDE if es_buena else COLOR_ROJO
            label_estado = "GOOD" if es_buena else "BAD"
            score = getattr(obj, 'score', None)
            label = (f"ID:{id_obj} C:{obj.carril} {label_estado}"
                     + (f" {score:.2f}" if score is not None else ""))
        else:
            color = COLOR_AMARILLO
            label = f"ID:{id_obj} C:{obj.carril}"

        cv2.rectangle(canvas, (bx1, by1), (bx2, by2), color, 2)
        cv2.circle(canvas, (bcx, bcy), 4, (0, 0, 255), -1)
        cv2.putText(canvas, label, (bx1, max(by1 - 5, 12)),
                    cv2.FONT_HERSHEY_SIMPLEX, 0.42, color, 1)

    # FPS en panel izquierdo
    cv2.putText(canvas, f"FPS Cam:{fps_camara:.1f}  YOLO:{fps_yolo:.1f}",
                (8, 22), cv2.FONT_HERSHEY_SIMPLEX, 0.55, (0, 255, 255), 2)

    # ── Separador vertical ─────────────────────────────────────────────
    cv2.line(canvas, (LP, 0), (LP, H), COLOR_LINEA_SEP, 2)

    # ── Panel derecho ─────────────────────────────────────────────────
    px = LP + 10   # x de inicio del texto
    py = 0         # y acumulador
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

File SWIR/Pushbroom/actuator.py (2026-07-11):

# =============================================================================
# actuator.py — Scheduler en Python + ejecutor serial para Arduino
# =============================================================================
# Arquitectura Vy:
#   Python es el único responsable del timing.
#   Arduino únicamente ejecuta órdenes inmediatas (L\n o R\n).
#
# Flujo:
#   encolar_evento() → cola Python → hilo scheduler espera CENTER_CROSSING_DELAY_S
#   → envía L\n o R\n al Arduino → Arduino mueve servo inmediatamente.
#
# Protocolo serial:
#   Python → Arduino: "L\n" (carril izquierdo) | "R\n" (carril derecho)
#   Arduino → Python: "READY\n" al iniciar | "FIRE:L\n" | "FIRE:R\n" | "CLOSE:L\n"
#
# Contrato de tiempo:
#   tiempo_cruce : obtenido con time.time() — timestamp absoluto para logs/CSV.
#   t_disparo    : obtenido con time.monotonic() — usado internamente por el
#                  scheduler para esperar con precisión, nunca para logs.
#   tiempo_programado : time.time() + delay_s — guardado al crear el evento
#                       para poder comparar programado vs real en CSV.
#
# Fail-safe:
#   Solo se encolan eventos BUENA (decisión en main.py).
#   Arduino sin cola ni timers → si pierde conexión, servos quedan en reposo.
# =============================================================================

import serial
import threading
import time
import queue
import csv
from dataclasses import dataclass, field
from typing import Optional, List
import config


@dataclass
class EventoActuador:
    """Evento de accionamiento pendiente en la cola del scheduler Python."""
    id_obj           : int
    carril           : int       # 1=izquierdo, 2=derecho
    etiqueta         : str       # "BUENA" — solo para log/CSV
    score            : float
    tiempo_cruce     : float     # time.time() del cruce — para logs y CSV
    t_disparo        : float     # time.monotonic() del disparo programado
    tiempo_programado: float     # time.time() + delay_s — para CSV


# Mapeo carril → comando serial
_CMD_CARRIL = {1: "L", 2: "R"}


class GestorActuadores:
    """
    Scheduler de disparos en Python + comunicación serial con Arduino.
    Arduino es un ejecutor inmediato: solo recibe L o R y mueve el servo.
    """

    def __init__(self):
        self._serial       : Optional[serial.Serial] = None
        self._cola         : queue.PriorityQueue = queue.PriorityQueue()
        self._running      : bool = False
        self._hilo_sched   : Optional[threading.Thread] = None
        self._hilo_ack     : Optional[threading.Thread] = None
        self._evento_sched : threading.Event = threading.Event()

        # Estadísticas
        self._disparos_enviados: int = 0
        self._errores_serial   : int = 0

        # Log CSV
        self._csv_file   = None
        self._csv_writer = None

    # ------------------------------------------------------------------
    # INICIALIZACIÓN
    # ------------------------------------------------------------------

    def iniciar(self) -> None:
        print(f"[ACTUATOR] Conectando Arduino en {config.ARDUINO_PORT} "
              f"@ {config.ARDUINO_BAUDRATE} bps...")

        try:
            self._serial = serial.Serial(
                port          = config.ARDUINO_PORT,
                baudrate      = config.ARDUINO_BAUDRATE,
                timeout       = config.ARDUINO_TIMEOUT_S,
                write_timeout = 1.0   # evita bloqueo infinito en write()
            )
            # Limpiar buffer antes de esperar READY
            self._serial.reset_input_buffer()
            self._esperar_ready(timeout_s=5.0)
            print("[ACTUATOR] Arduino conectado y listo.")
        except serial.SerialException as e:
            print(f"[ACTUATOR] ERROR al conectar Arduino: {e}")
            print("[ACTUATOR] El sistema continuará SIN control de servos.")
            self._serial = None

        # Log CSV
        if config.LOG_TO_CSV:
            try:
                self._csv_file = open(config.LOG_CSV_PATH, 'w',
                                      newline='', encoding='utf-8')
                self._csv_writer = csv.writer(self._csv_file)
                self._csv_writer.writerow([
                    'timestamp_real', 'id_obj', 'carril', 'etiqueta',
                    'score', 'tiempo_cruce', 'tiempo_programado',
                    'retardo_real_s'
                ])
                print(f"[ACTUATOR] Log CSV: {config.LOG_CSV_PATH}")
            except Exception as e:
                print(f"[ACTUATOR] No se pudo crear CSV: {e}")

        self._running = True

        # Hilo scheduler
        self._hilo_sched = threading.Thread(
            target=self._hilo_scheduler,
            name="hilo_actuador_sched",
            daemon=True
        )
        self._hilo_sched.start()

        # Hilo ACK — solo si hay conexión serial y ACK habilitado
        if self._serial is not None and config.ARDUINO_ACK_ENABLED:
            self._hilo_ack = threading.Thread(
                target=self._hilo_leer_ack,
                name="hilo_actuador_ack",
                daemon=True
            )
            self._hilo_ack.start()
        elif self._serial is not None:
            print("[ACTUATOR] Hilo ACK deshabilitado "
                  "(ARDUINO_ACK_ENABLED=False en config.py).")

        print("[ACTUATOR] Scheduler iniciado.")

    def _esperar_ready(self, timeout_s: float = 5.0) -> None:
        """Espera el mensaje READY del Arduino con timeout."""
        t0 = time.time()
        while time.time() - t0 < timeout_s:
            try:
                linea = self._serial.readline().decode('ascii', errors='ignore').strip()
                if linea == "READY":
                    print("[ACTUATOR] Arduino READY.")
                    return
            except serial.SerialException:
                break
        print("[ACTUATOR] ADVERTENCIA: no se recibió READY del Arduino "
              f"en {timeout_s}s — continuando de todas formas.")

    # ------------------------------------------------------------------
    # ENCOLAR EVENTO
    # ------------------------------------------------------------------

    def encolar_evento(
        self,
        id_obj      : int,
        carril      : int,
        etiqueta    : str,
        score       : float,
        tiempo_cruce: float
    ) -> None:
        """
        Encola un evento de disparo.

        Args:
            id_obj       : ID del objeto clasificado
            carril       : 1 (izquierdo) o 2 (derecho)
            etiqueta     : "BUENA" — informativo para logs
            score        : probabilidad del clasificador
            tiempo_cruce : time.time() del cruce de línea virtual

        El scheduler esperará CENTER_CROSSING_DELAY_S desde este instante
        antes de enviar el comando al Arduino.
        """
        delay_s           = max(0.0, config.CENTER_CROSSING_DELAY_S)
        t_disparo         = time.monotonic() + delay_s
        tiempo_programado = time.time() + delay_s
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

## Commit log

2026-07-11 Estado inicial del proyecto antes de reorganización
    [box.stl, top.stl]
2026-07-11 docs: documenta la estructura general del proyecto
